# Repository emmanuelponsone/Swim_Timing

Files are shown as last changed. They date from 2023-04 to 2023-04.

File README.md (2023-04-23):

# Swimming Races timing system
Timing project for Swimming Races

**Watch video of the system working on field:**

https://youtu.be/FMHkYDIDqnM

Complete development of software and hardware for a system designed to meet the precision timing requirements of the international swimming federation. 

The software development involved:
- Development of firmware in C for 1 master microcontroller and 8 slave microcontrollers (ARM LPC1343 - Cortex M3).
- The master microcontroller reads a high-frequency timebase which is then divided and distributed to the slaves for synchronization.
- The slave microcontrollers, one for each lane of the pool, receive the synchronization signal as an interrupt and measure the time between button presses at the ends of the pool. The time data is reported to the master microcontroller.
- The master microcontroller receives the data from the slaves and sends the data to a PC via USB port.

On the PC:
- The PC software is responsible for managing the database and runs on a web environment on a RAILS server.
- Development of software in Ruby on Rails to create and maintain the database and display information on a web browser.
- Creating new scenarios (pools, length of each lane, number of lanes, laps per competition)
- Managing swimmers (age, gender, category, time records for each swim style, etc.)

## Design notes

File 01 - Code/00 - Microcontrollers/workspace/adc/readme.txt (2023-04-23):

adc
=====================
This project contains an ADC example for an LPCXpresso board.

It samples each ADC channel and plots the results in an ASCII
bargraph in the LPCXpresso Console using semihosted printf.

The project makes use of code from the following library project:
- CMSISv1p30_LPC13xx : for CMSIS 1.30 files relevant to LPC13xx

This library project must exist in the same workspace in order
for the project to successfully build.

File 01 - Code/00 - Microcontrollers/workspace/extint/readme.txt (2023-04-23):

extint
=====================
This project contains an external interrupt example for the LPCXpresso
board mounted with an LPC1343 Cortex-M3 part.

When downloaded to the board and executed, LED2 will be illuminated.
Then each time an external interrupt is triggered - by connecting P2.1
to ground - the state of LED2 will toggle.

The project makes use of code from the following library project:
- CMSISv1p30_LPC13xx : for CMSIS 1.30 files relevant to LPC13xx

This library project must exist in the same workspace in order
for the project to successfully build.

For more details, read the comments in config.h

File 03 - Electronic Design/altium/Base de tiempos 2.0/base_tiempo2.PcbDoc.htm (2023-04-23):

Reporting Options

# File in Previous Format

Date | : | 23/4/2023
Time | : | 13:04:47
Filename | : | C:\Users\hebertiponsone\Downloads\proyectofinal\altium\Base de tiempos 2.0\base_tiempo2.PcbDoc

Version | Warning
Summer 09 | CAUTION - File contains old violation objects. These violations are no longer supported & will not be loaded. Please run DRC after opening this file in order to refresh the violations.
Summer 09 | CAUTION - Existing testpoint rules and settings are used as fabrication testpoint information.
Release 12 | CAUTION - Air Gap Width previously controlled by Clearance rule is now controlled by Polygon Connect Style rule's newly introduced Air Gap Width (set to default value). Suggest reviewing each Polygon Connect Style rule's Air Gap Width attribute for correctness.
Release 13 | CAUTION - Silkscreen Over Component Pads Rules are converted to Silk To Solder Mask Clearance Rules. Suggest examining rule scopes for accuracy.

This file was generated by an earlier version of the software

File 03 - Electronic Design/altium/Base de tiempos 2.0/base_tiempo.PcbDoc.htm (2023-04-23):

Altium Reporting Options

# File in Previous Format

Date | : | 26/03/2012
Time | : | 10:34:26 a.m.
Filename | : | C:\Users\Emmanuel\Dropbox\proyectofinal\altium\Base de tiempos 2.0\base_tiempo.PcbDoc

Version | Warning
Summer 09 | CAUTION - File contains old violation objects. These violations are no longer supported & will not be loaded. Please run DRC after opening this file in order to refresh the violations.
Summer 09 | CAUTION - Existing testpoint rules and settings are used as fabrication testpoint information.

This file was generated by an earlier version of the software

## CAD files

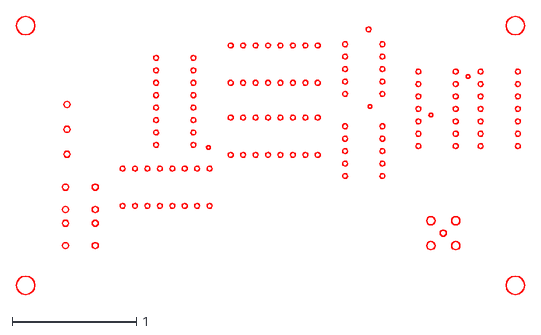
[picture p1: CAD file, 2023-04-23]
03 - Electronic Design/altium/Base de tiempos 2.0/agujeros_btiempos.dxf
4.09 x 2.24

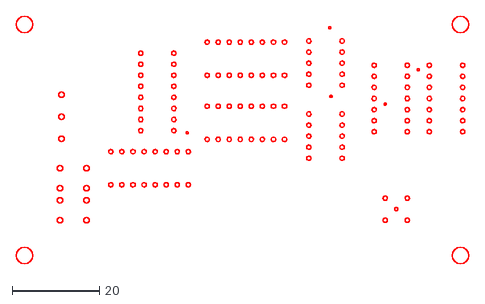
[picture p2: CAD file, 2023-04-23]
03 - Electronic Design/altium/Base de tiempos/cam.dxf
103.9 x 56.9

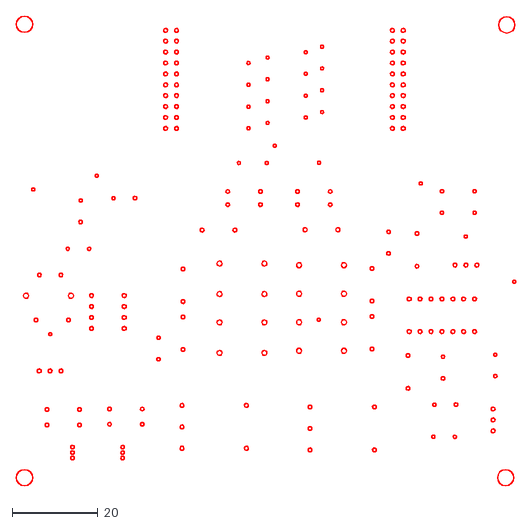
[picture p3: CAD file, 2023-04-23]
03 - Electronic Design/altium/caja de conexion/cam.dxf
116.4 x 109.5

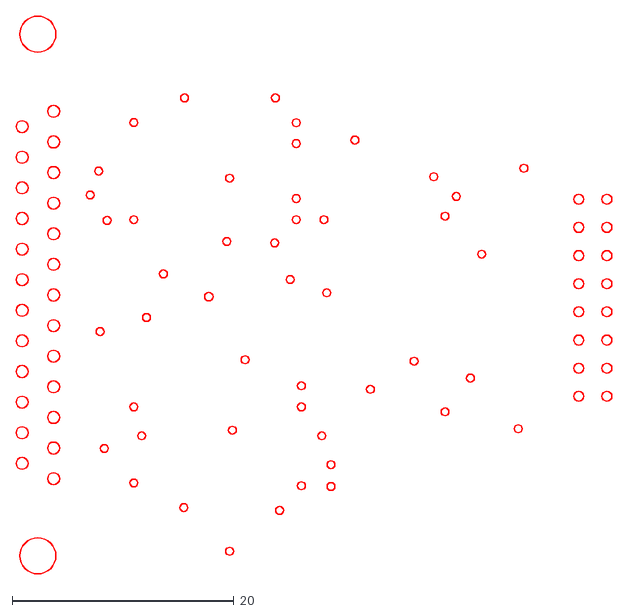
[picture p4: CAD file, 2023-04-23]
03 - Electronic Design/altium/Conexion unidad central/Filminas/adaptador lado unidad central/cam.dxf
53.7 x 50.3

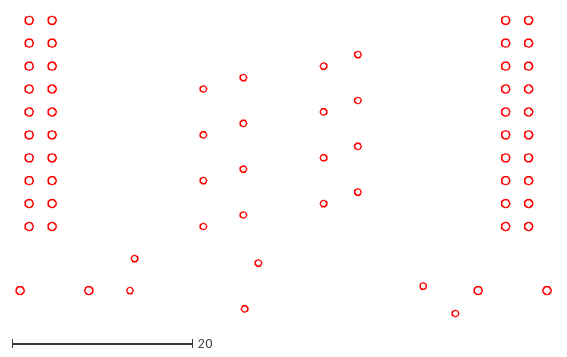
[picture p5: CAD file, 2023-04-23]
03 - Electronic Design/altium/Conexion unidad central/Filminas/caja de conexion/cam.dxf
59.3 x 33.3

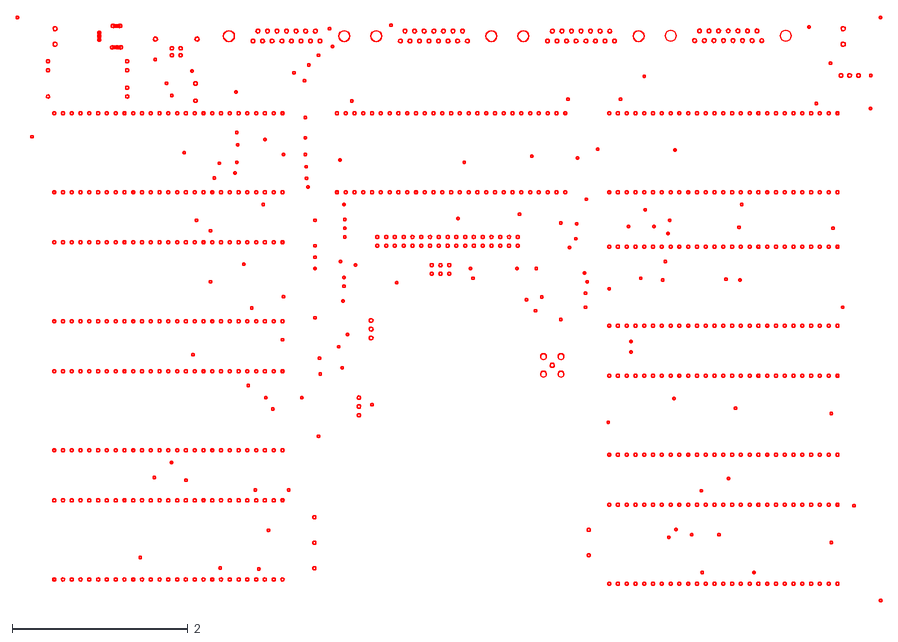
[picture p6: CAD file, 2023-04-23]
03 - Electronic Design/altium/Placa madre 2.0/filminas y nc drill/agujeros_placa_madre.dxf
9.86 x 6.67

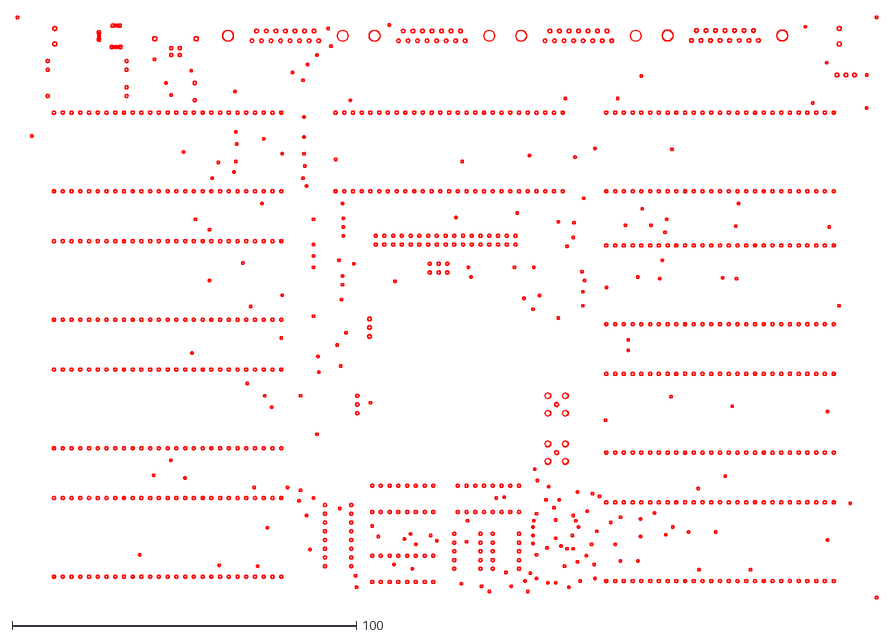
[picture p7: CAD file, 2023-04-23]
03 - Electronic Design/altium/Placa madre/filminas/cam.dxf
250.5 x 169.4

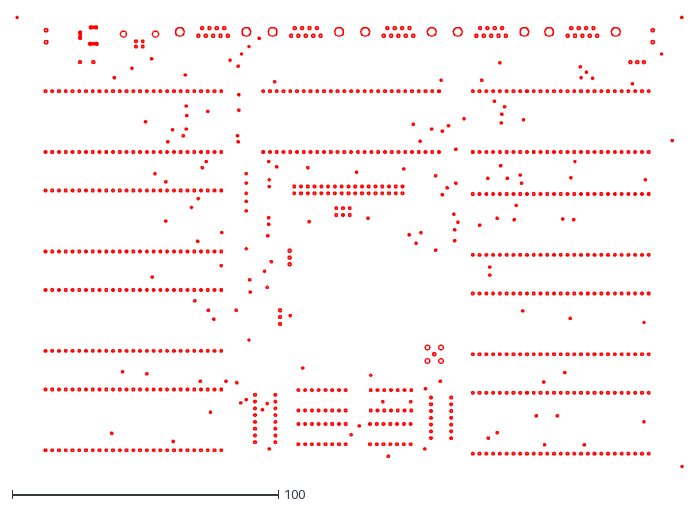
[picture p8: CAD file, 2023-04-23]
03 - Electronic Design/altium/Placa madre 2.0/cam.dxf
250.5 x 169.4

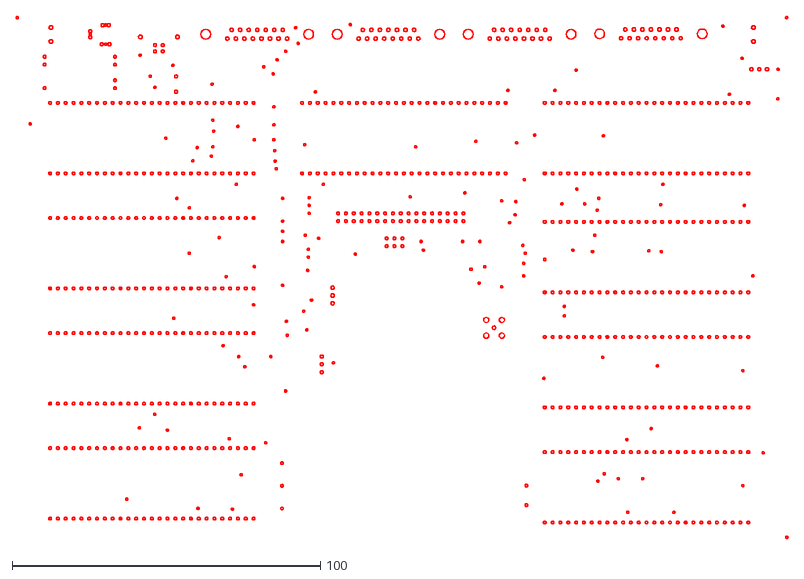
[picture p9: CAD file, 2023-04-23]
03 - Electronic Design/altium/Placa madre 2.0/agujeros_23.dxf
250.5 x 169.4

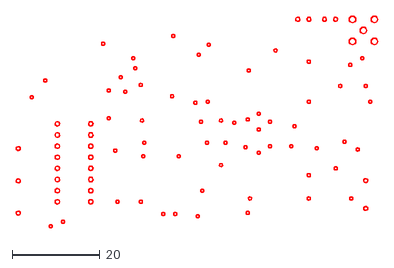
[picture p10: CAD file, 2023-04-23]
03 - Electronic Design/altium/Base de tiempos 2.0/agujeros.dxf
82.5 x 48.3

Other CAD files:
03 - Electronic Design/altium/Base de tiempos 2.0/agujeros_26_3.dwg
03 - Electronic Design/altium/Conexion unidad central/Filminas/adaptador lado unidad central/cam.dwg
03 - Electronic Design/altium/Conexion unidad central/Filminas/caja de conexion/cam.dwg
03 - Electronic Design/altium/Placa madre 2.0/agujeros_23.dwg
03 - Electronic Design/altium/Placa madre/filminas/cam.dwg

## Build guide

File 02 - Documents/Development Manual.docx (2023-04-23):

### tabla de contenidos

Desarrollo 2

Base de tiempos 3

Microcontroladores 6

Esquema general del sistema 8

PCB, esquemáticos y conexiones 9

Sistema operativo 10

Software 11

Placas de toque y pulsadores 12

Cables y conectores 14

Terminaciones en acrílico 15

Anexo: Código fuente 16

### desarrollo

El objetivo del presente texto es trazar una línea que una los primeros esbozos del proyecto con sistema terminado, justificando decisiones tomadas tanto en el ámbito técnico como en el económico del proyecto.

La idea surgió luego de tomar cuenta de la ausencia en el mercado de un sistema de cronometraje de natación de origen nacional que pueda satisfacer las demandas de una porción de mercado que no tiene acceso a equipos importados de elevado costo. Es así que se decidió apuntar a pequeños clubes, profesores de natación e instituciones deportivas barriales y/o comunales.

El primer punto a resolver fue entonces conocer las necesidades de estos potenciales clientes. Luego de realizar una encuesta a cerca de 30 profesores de natación, surgieron las siguientes características con las que debía contar el producto:

- La precisión en la toma de tiempos debía necesariamente compararse con los equipos profesionales, ya que los nadadores interesados en competir semi profesionalmente o profesionalmente van a llevar a cabo sus competencias en lugares donde se encuentren equipos profesionales homologados por la FINA y por lo tanto, el equipo con el que realicen sus entrenamientos debe registrar fielmente los tiempos de los mismos así como también poseer mecanismos de acción similares para facilitar la transferencia.
- El equipo no necesita estar homologado, ya que no va a ser utilizado para tomar tiempos oficiales.
- El manejo del equipo debe ser simple tanto en su hardware como en su software.
- El software debe permitir la gestión de una base de datos con la información de los nadadores, estilos, tiempos, etc.
- El equipo debe ser modular, es decir, tener la posibilidad de equipar desde un andarivel hasta ocho, para adaptarse a las necesidades económicas de cada cliente. Dicho de otra forma, que aquel que pueda equipar un solo andarivel, lo pueda hacer y con el tiempo ir añadiendo equipamiento para más andariveles.
- La seguridad de las personas apareció en reiteradas encuestas como una prioridad debido a que el equipo funcionará en ambientes de alta humedad.

Siguiendo estos lineamientos generales se comenzó con el desarrollo del proyecto.

### base de tiempos

La elección de la base de tiempos fue el aspecto técnico más importante a ser resuelto. El reglamento de natación de la FINA (Federación Internacional de Natación) en su inciso SW 11.2 fue lo que nos marcó las especificaciones con las que debía contar la base de tiempos. Dicha regla establece que el equipo debe ser capaz de garantizar el milisegundo aunque para la tabla de posiciones se usen las centésimas de segundo. Así, por ejemplo, tomando una carrera de 10 minutos de duración, el equipo debe tener una incertidumbre en la toma de tiempos menor a 10ppm, lo que equivale a decir que en esos 10 minutos, la incertidumbre sea menor a 1 milisegundo.

Surgió como primera opción utilizar un temporizador de un microcontrolador para llevar a cabo la toma de tiempos, sin embargo no cumplía con las condiciones propuestas por poseer una incertidumbre demasiado elevada, del orden de las 100ppm.

La solución adoptada fue la de diseñar una base de tiempos cuyo oscilador de referencia tuviese una incertidumbre menor a 10ppm. Luego de buscar varios modelos encontramos que el modelo que mejor se adaptaba a nuestras necesidades (principalmente debido a la deriva térmica) era el modelo FOX 924 (10MHZ – 2.5ppm). Se muestra a continuación los datos más relevantes del mismo:

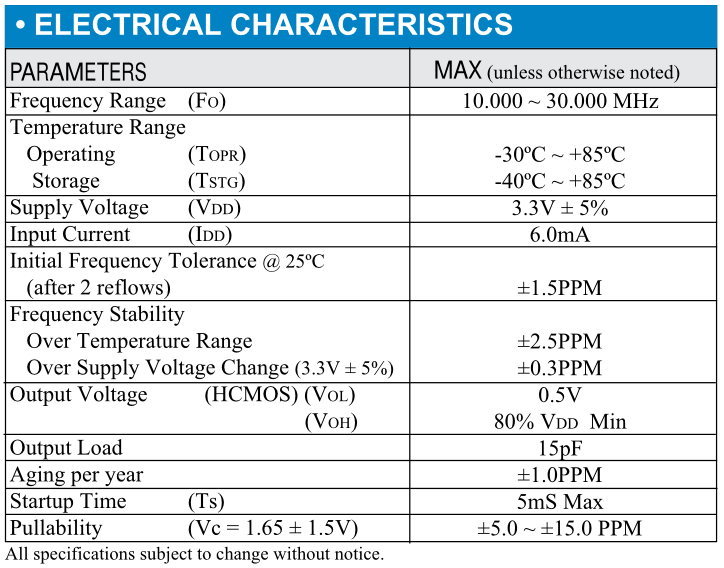
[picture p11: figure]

Ilustración 1: Especificaciones del Oscilador de Referencia

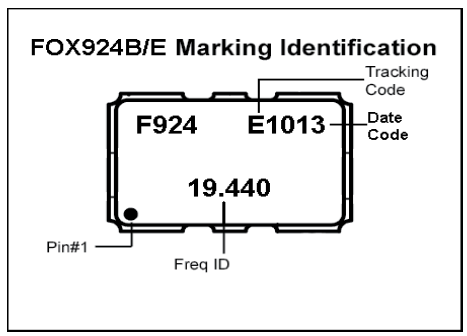
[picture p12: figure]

Ilustración 2: Layout del Oscilador

Si bien aún no habíamos tomado la decisión sobre qué microcontrolador utilizar, ya teníamos en claro que era imposible atacarlo con una base de tiempos de 10MHz y que debíamos bajar la frecuencia de la misma. Para ello se diseño un sistema de división de frecuencias basado en un contador binario de 14 bits seguido de una función lógica lograda mediante compuertas para reducir los 10MHz a 10KHz, frecuencia que resulta razonable para casi cualquier microcontrolador presente en el mercado actual. El esquema de división de frecuencias se presenta a continuación:

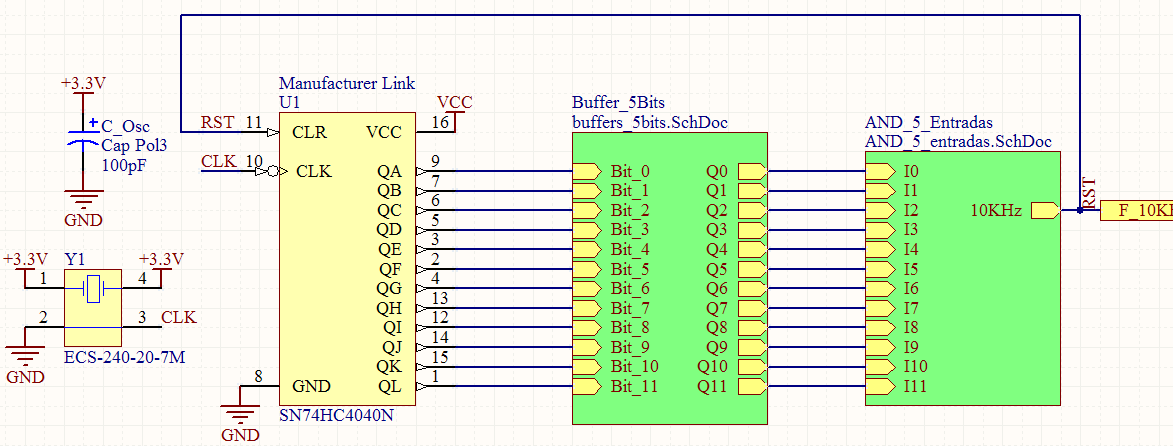
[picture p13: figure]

Ilustración 3: Esquemático de la Base de tiempos

Luego de fabricar un prototipo de la base de tiempos, se procedió a realizar las mediciones correspondientes para verificar si cumplía con las especificaciones.

Las mediciones se realizaron con un contador Tektronix CMC251, cuyas características son las siguientes:

- Número de dígitos: 8 más indicador de desborde.
- Frecuencia de la base de tiempo: 10MHz
- Incertidumbre de la base de tiempo: +/-1ppm
- Envejecimiento de la base de tiempo: +/-1ppm por año.
- Tiempo desde la adquisición del equipo: 5 años.

El objetivo de la medición era determinar la frecuencia del oscilador utilizado en el sistema de cronometraje de natación y poder evaluar si cumplía con los requisitos del proyecto. Recordemos que la máxima incertidumbre admitida es de +/-10ppm.

Esto significa que, al ser la frecuencia nominal del oscilador igual a 10MHz, se debe garantizar que el valor verdadero se encuentre en el intervalo 10MHz +/-10ppm. Es decir:

Fmin=10MHz-0.000100MHz=9.999900MHz

Fmax=10MHz+0.000100MHz=10.000100MHz

En resumen, buscábamos que la medición a realizar no solamente poseyera su valor nominal dentro de este intervalo, sino también que la ventana delimitada por la incerteza de la medición se encontrara dentro del intervalo requerido por el proyecto. De esta manera nos asegurábamos el cumplimiento de las especificaciones.

Para obtener máxima resolución y mínimo error en las mediciones se utilizó el frecuencímetro en modo frecuencia con un tiempo de compuerta de 10 segundos.

Como para este modo de operación, siendo la frecuencia incógnita aproximadamente 10Mhz, se contarán en 10 segundos 100 millones de pulsos, por lo tanto, el dígito más significativo se pierde, pero se sabe que es igual a la unidad. Dicho esto, el resultado de la medición fue:

f_(medida) =10.0000033MHz

Si ahora tenemos en cuenta que el error relativo de este instrumento se puede expresar como:

(∆f_x)/(f_x)=(∆f_(bt))/(f_(bt))+1/N

Siendo:

(∆f_(bt))/(f_(bt)):Error relativo de la base de tiempo del instrumento

1/N:Error de cuentización del insturmento. N:número de cuentas

Recordando que el error en la base de tiempo para el equipo recién calibrado es de +/-1ppm y que el equipo tiene 5 años de antigüedad, el error relativo total es de 6ppm.

Por último, el número de cuentas, N, es:

N=100000033→1/N≅0.001ppm

Por lo tanto, la incertidumbre relativa es:

(∆f_x)/(f_x)=6ppm+0.001ppm≅6ppm

Ahora podemos expresar el resultado de la medición como:

f_x =10.0000033MHz ±0.000060MHz

Del mismo pudimos concluir que la base de tiempos cumplía holgadamente con las especificaciones y, por lo tanto, era posible seguir avanzando en el proyecto teniendo total confianza en la calidad de uno de sus módulos críticos.

### microcontroladores

Era tiempo ahora de decidir sobre el tipo y el número de microcontroladores a utilizar. El primer esquema contemplaba el uso de un único microcontrolador el cual debía encargarse de:

- Comunicarse con la PC.
- Contar los pulsos de la base de tiempo.
- Recibir las señales de los 4 pulsadores de cada andarivel, es decir, un total de 32 pulsadores para el caso de 8 andariveles completos.
- Para cada andarivel contar los pulsos de la base de tiempos y registrar los tiempos cuando llegue cada señal de los pulsadores.
- Decidir para cada andarivel si daba prioridad a los pulsadores manuales o a las placas de toque.
- Recibir la señal del pulsador de largada, accionar la señal de largada.

Evidentemente las tareas a realizar eran demasiadas para ser llevadas a cabo por un único microcontrolador. Por ello se decidió utilizar un esquema en el que cada andarivel tendría asociado un microcontrolador el cual debería realizar las siguientes tareas:

- Recibir las señales de las dos placas de toque y de los dos pulsadores manuales.
- Contar los pulsos de la base de tiempos.
- Registrar los tiempos al momento de las pulsaciones.
- Comunicarse con un microcontrolador maestro para transmitirle los tiempos registrados.

Por otro lado, se contaría también, con un microcontrolador maestro, el cual se encargaría de realizar la sincronización de la unidad central y resolver las siguientes tareas:

- Comunicarse con la PC para enviar datos y recibir.
- Comunicarse con las unidades de cada andarivel para solicitar los tiempos de cada andarivel y transmitirle ciertos datos antes de comenzar la toma de tiempos.
- Registrar la señal de largada.

Con este nuevo esquema resulta razonable la carga asociada a cada microcontrolador al mismo tiempo que se garantiza la correcta adquisición de los datos.

Resumiendo, se optó por una unidad central que aloje a los 9 microcontroladores, que sea capaz de comunicarse con la PC y a la cual se conecten todos los pulsadores del sistema (Pulsadores manuales, placas de toque y señal de largada).

Una vez elegido el esquema a utilizar se procedió a seleccionar el tipo de microcontrolador. Como los miembros del grupo teníamos ya experiencia en la programación de la familia 8051 se optó en primera instancia por un Silabs F350.

Sin embargo, era necesario que el sistema se conectara a la PC mediante un puerto USB teniendo en cuenta la amplia difusión de este puerto en la gran mayoría de las computadoras. Lo cual no resultadaza para nada sencillo utilizando este tipo de microcontrolador. Por otro lado, la frecuencia de operación de este dispositivo no supera los 8MHz, valor que resulta algo justo teniendo en cuenta que las unidades dedicadas a cada andarivel no pueden darse el lujo de perder ni siquiera un pulso de la base de tiempos.

Estos inconvenientes llevaron a elegir un microcontrolador ARM, más precisamente, el LPC1343 que se consigue en el mercado local junto con su placa de desarrollo y programación por unos $120, evitando así tener que desarrollar una placa para alojar al dispositivo, ahorrando tiempo y dinero.

Entre las características que más nos interesaron de este sistema fueron:

- Facilidad de implementación de comunicación USB.
- Facilidad de implementación de la comunicación entre microcontroladores.
- Frecuencia de operación de 72MHz.
- Facilidad de programación.
- Precio.
- Calidad del PCB.
- Disponibilidad en el mercado local.

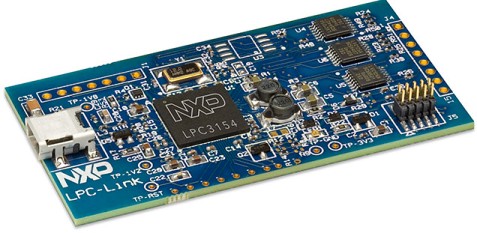
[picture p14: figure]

Ilustración 4: Programador del microcontrolador

### esquema general del sistema

Con la base de tiempos resuelta y los microcontroladores elegidos, procedimos a diseñar el esquema general del sistema, el cual se muestra a continuación:

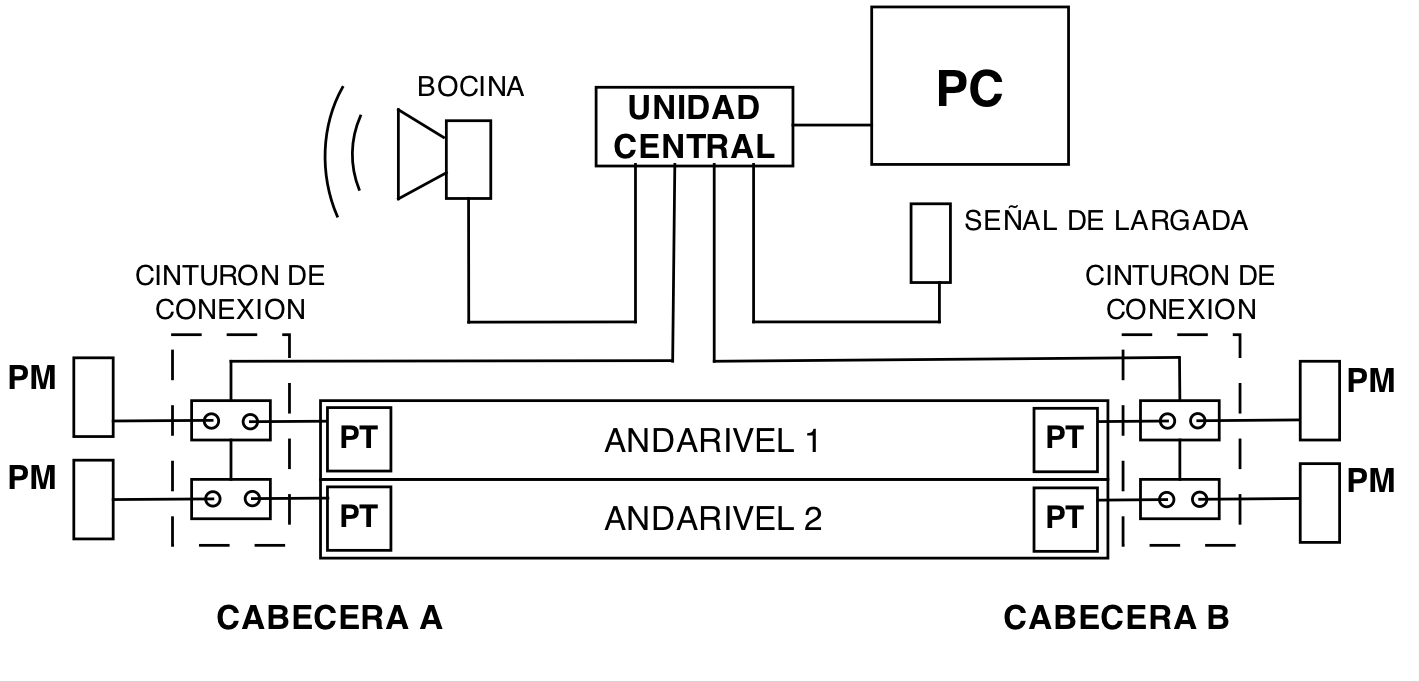
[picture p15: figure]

Ilustración 5: Esquema general del sistema

Se puede observar que la configuración adoptada es similar a la de los sistemas comercializados internacionalmente. Dicha decisión surgió como un lineamiento importante luego de realizar la encuesta a profesores y entrenadores de natación cuando, en resumen, mencionaron que se obtienen mejores rendimientos deportivos si durante los entrenamientos se consigue simular de la forma más aproximada el entorno de la competencia. Entendiéndose por ello placas de toque y bocina de largada entre otras cuestiones relacionadas más bien al estado mental del atleta.

### PCB, esquematicos y conexiones

Teniendo en cuenta que se decidió utilizar nueve módulos NXP LPC1343 surgió el problema del tamaño que debería tener el circuito impreso para alojarlos. El límite para el tamaño del circuito impreso está impuesto por el método serigráfico utilizado para su fabricación, es así que se puede alcanzar el tamaño de una hoja A4, es decir 30cm de alto por 21cm de ancho. Luego se procedió a la elección del gabinete teniendo en cuenta las medidas anteriores.

Con esta limitación se procedió a diseñar el circuito impreso, cuya versión final se muestra a continuación:

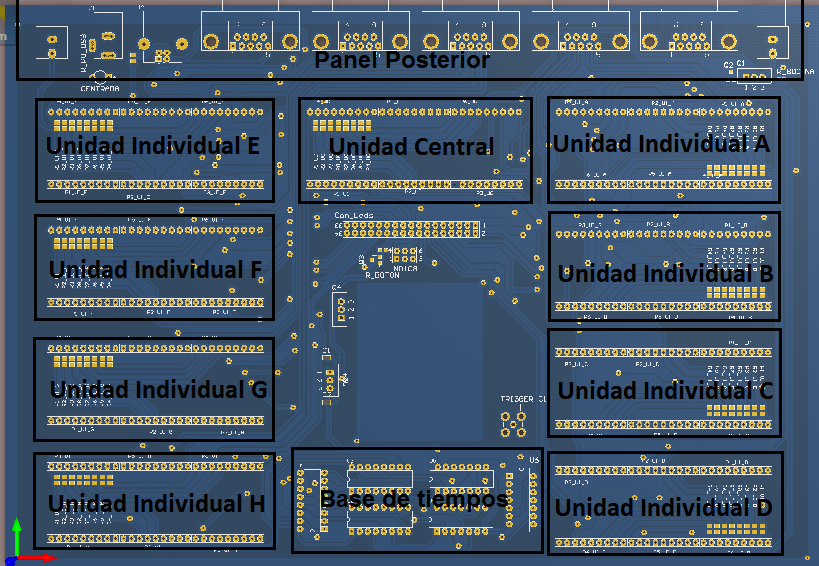
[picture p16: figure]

Ilustración 6: Vista frontal del Circuito impreso

Las conexiones en el panel posterior del gabinete se definieron como se muestra en la siguiente imagen:

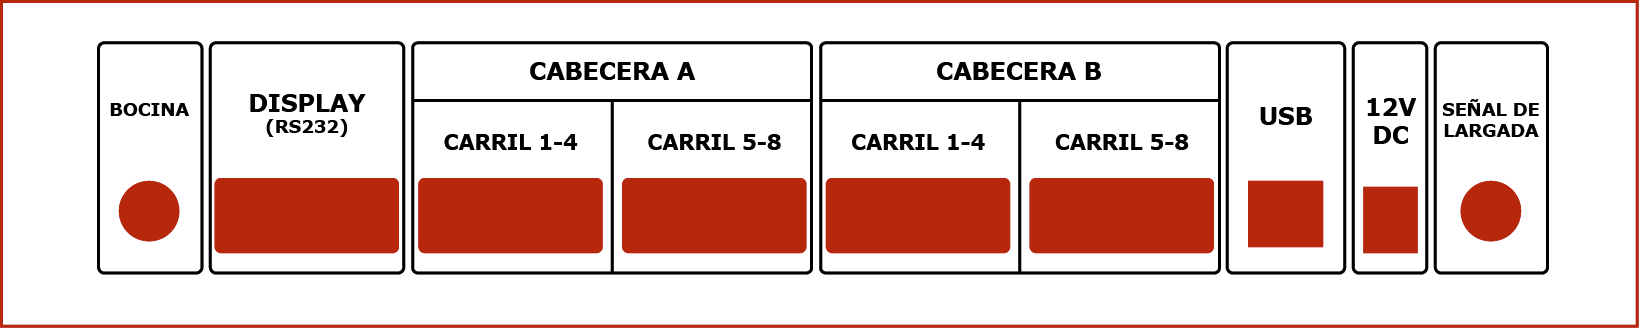
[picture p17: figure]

Ilustración 7: Vista del panel trasero

El diseño de los esquemáticos se realizó en Altium Designer Winter. Los distintos esquemáticos se muestran en las páginas siguientes.

### sistema operativo

La elección del SO resulto ser otro de los grandes problemas con el que nos encontramos, ya que si bien el sistema operativo más difundido es Windows, es Linux el que ofrece más posibilidades a la hora de programar y de realizar conexiones con dispositivos no convencionales, no requiere de drivers para manejar un puerto USB, etc.

Si bien los usuarios no suelen estar familiarizados con Linux, su uso se limitaría simplemente a utilizar el software provisto con el sistema de cronometraje, por lo que para el usuario no sería un problema mayor y para nosotros, sería mucho más simple la programación y conexión de los dispositivos. En definitiva, el usuario debería aprender a manejar solamente el programa, situación que sería igual en Windows, Linux u otro sistema operativo ya que se trata de una aplicación Web. Lo cual se traduce a que la operación del programa exactamente igual a navegar por Internet.

La distribución adoptada de Linux es la que se conoce como la más amigable de todas por poseer un entorno grafico muy intuitivo y depurado. La misma se llama Ubuntu y se ha comenzado a instalar en varios equipos de tiendas de electrodomésticos que venden computadoras por ser una alternativa legal y completa para cualquier uso, ya sea domestico o profesional.

### software

Este ítem resulta de especial importancia ya que es con el software de la PC con el que el usuario deberá interactuar, por lo tanto debe ser ágil, simple de utilizar y confiable.

En un primer momento se debió seleccionar un lenguaje o entorno de programación que nos permita hacer una interfaz grafica de usuario y que al mismo tiempo nos permita interactuar con bases de datos para guardar de forma ordenada los datos obtenidos.

Luego de presenciar una competencia de cierta importancia comprendimos que una herramienta muy útil sería utilizar Internet para la organización de las partidas del evento deportivo.

Con estos tres requerimientos presentes dimos con el entorno de desarrollo Web llamado Ruby on Rails, el cual permite crear grandes aplicaciones para Internet de forma sencilla, permitiendo a su vez interactuar con bases de datos a través de muchas herramientas completas y fáciles de usar.

El desarrollo de la aplicación se realizó en dos etapas bien diferenciadas. En la primera se buscó crear un núcleo capaz de crear, leer, modificar y destruir información en las tablas de la base de datos. Tarea sencilla pues para estos fines es que el entorno de Ruby on Rails fue pensado.

En una segunda etapa se busco desarrollar un medio por el cual la aplicación pueda tener una comunicación bidireccional con la Unidad Central, comenzando con transferencias sencillas y luego aumentando gradualmente la complejidad. En esta instancia se recurrió al lenguaje de programación C para crear un programa que se comunique con la Unidad Central y esta le transfiera los datos solicitados, escribiéndolos más tarde en un archivo para su posterior lectura. A continuación se muestra el esquema de comunicación:

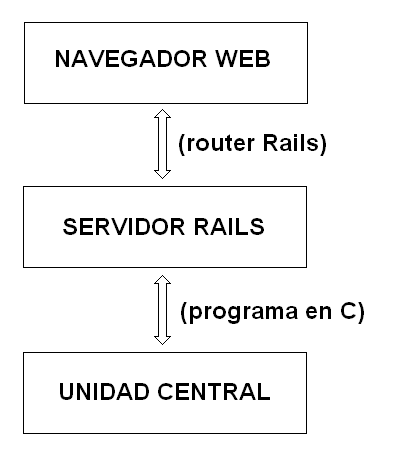
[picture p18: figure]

### Placas de toque y pulsadores

La placa de toque, al ser un dispositivo mecánico, fue el que más trabajo y dolores de cabeza nos dió, ya que nuestra especialidad es la electrónica, no la mecánica ni la carpintería.

Si bien ya teníamos cierta experiencia con este tipo de placas, ya que en un emprendimiento particular habíamos desarrollado una sistema de medición de saltos pliométricos, en el cual el deportista debe saltar sobre una plataforma la cual oficia también como pulsador, en nuestro caso la situación era distinta pues la placa de toque debería trabajar en el agua de forma semi-sumergida, ser impermeable, soportar los golpes del deportista y no activarse con el oleaje.

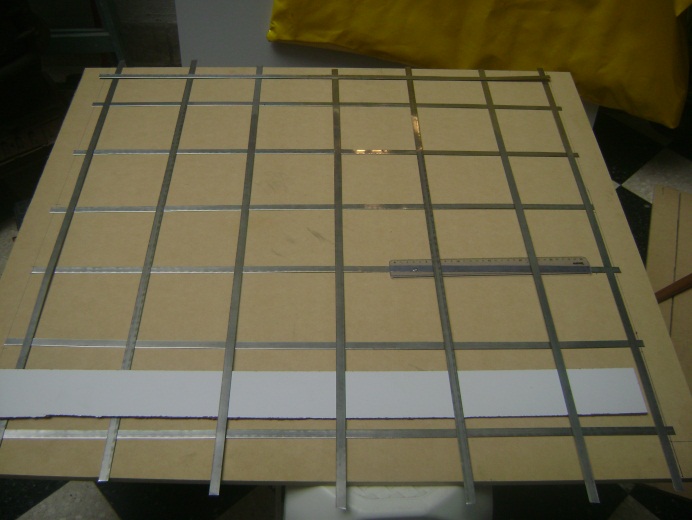
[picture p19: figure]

Se optó por construirla con dos placas paralelas de 1.1mts por 0.9mts de distinto grosor, el material ideal para la construcción de las placas es el PVC dada su durabilidad y características mecánicas, sin embargo, por su costo (aproximadamente $1500 para el par de placas) se optó por hacer el prototipo con placas de madera MDF. Cada placa alojaría varillas de acero inoxidable separadas equidistantemente, como se muestra a continuación:

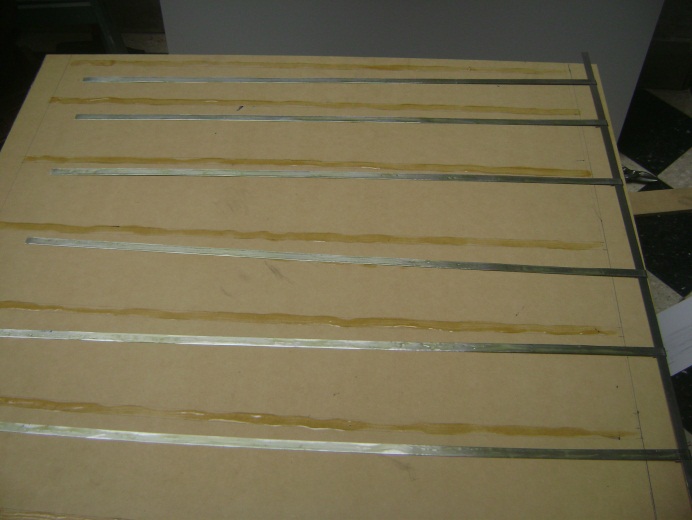
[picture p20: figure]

Ilustración 8: Vistas de las placas de toque

Para separar las placas y permitir que el pulsador funcione como normal abierto se utilizaron resortes dispuestos de la siguiente manera:

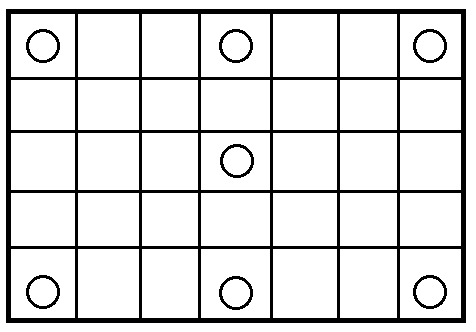
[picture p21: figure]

Ilustración 9: Esquema de posicionamiento de los resortes de separación

Por último, se unen las placas mediante bisagras tipo libro, las cuales le dan rigidez mecánica y facilidad de apertura a la hora de realizar reparaciones, protegiendo al mismo tiempo las soldaduras del cable con las varillas de acero inoxidable.

La funda, por otro lado, se envió a fabricar en un material sintético de alta resistencia (similar al de las bolsas de boxeo) cuyas uniones se realizan por costura y termo sellado, lo cual garantiza la impermeabilidad de la funda a la vez que su resistencia se ve mejorada. En la misma funda hay un compartimiento por donde pasar un caño para sujetar la placa de toque. La sujeción va a depender del natatorio donde se vaya a instala el equipo, por lo tanto es un ítem a solucionar en la etapa de instalación.

### cables y conectores

Los cables y los conectores utilizados tanto para las placas de toque como para los pulsadores manuales se ven expuestos no solo a condiciones de gran humedad, sino también de posibles pisadas por parte de los competidores y jueces. Por lo tanto se optó por la línea XLR, utilizados en lugares de alto tránsito y sometidos a esfuerzos considerables, como por ejemplo recitales. Son cables robustos, que al pisarlos y apretarlos no sufren daños. Sus conectores son realmente robustos, poseen ranuras que hacen imposible la tarea de conectarlo de manera errónea con lo cual resultan ideales para personal no calificado. Se muestran imágenes a continuación:

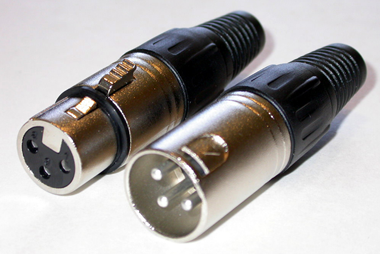
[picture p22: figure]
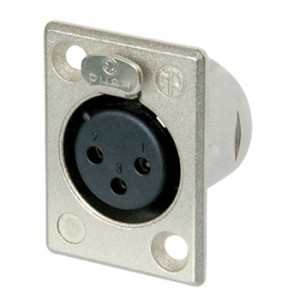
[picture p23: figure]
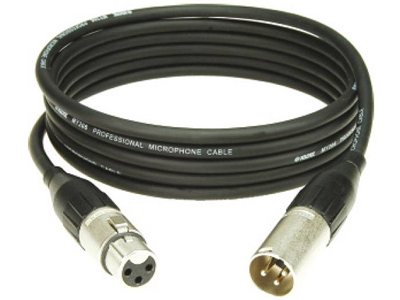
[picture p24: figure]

Ilustración 10: Conectores XLR

Para alojar los conectores dentro de las cajas de conexiones se diseñaron placas de montaje en aluminio las cuales fueron mecanizadas utilizando una CNC. Este último detalle permite darle mayor robustez al conjunto, cuestión que resulta ideal para encontrarse en un ambiente hostil.

### terminaciones en acrilico

Para terminar de darle al proyecto un aspecto más cuidado estéticamente y facilitar su uso se diseñaron frentes y piezas en acrílico para el gabinete y los pulsadores:

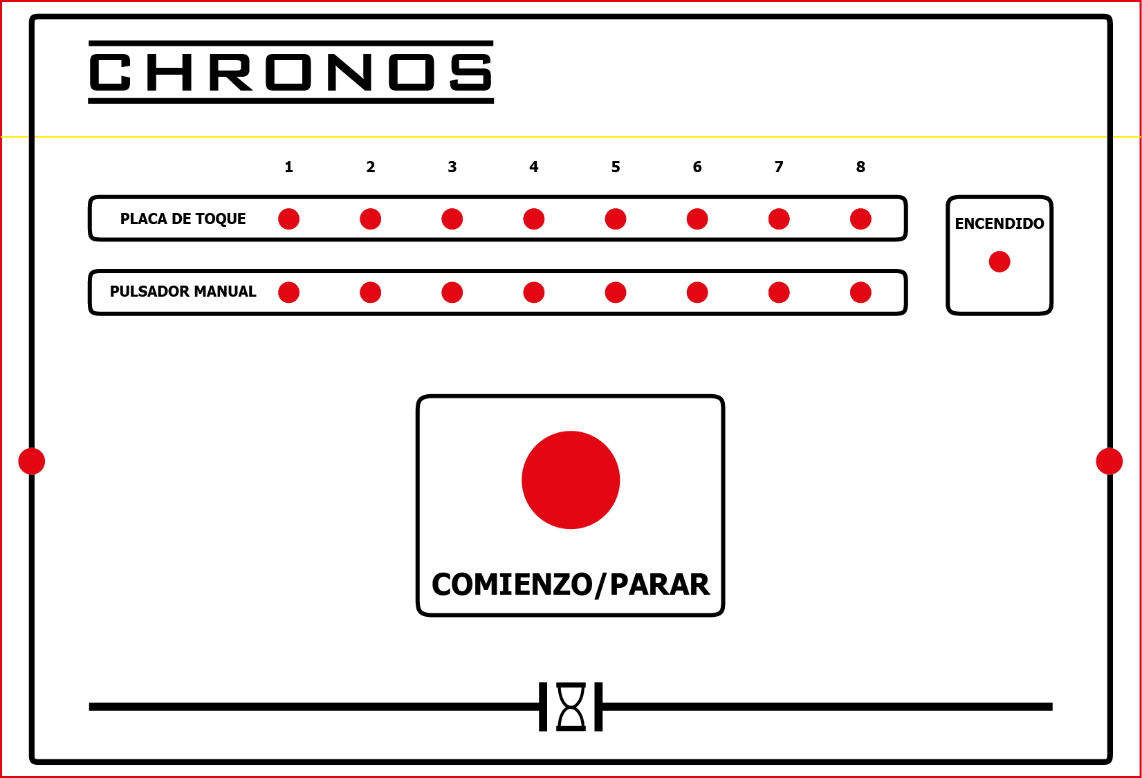
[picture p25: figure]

Ilustración 11: Diseño del Frente del gabinete en acrílico

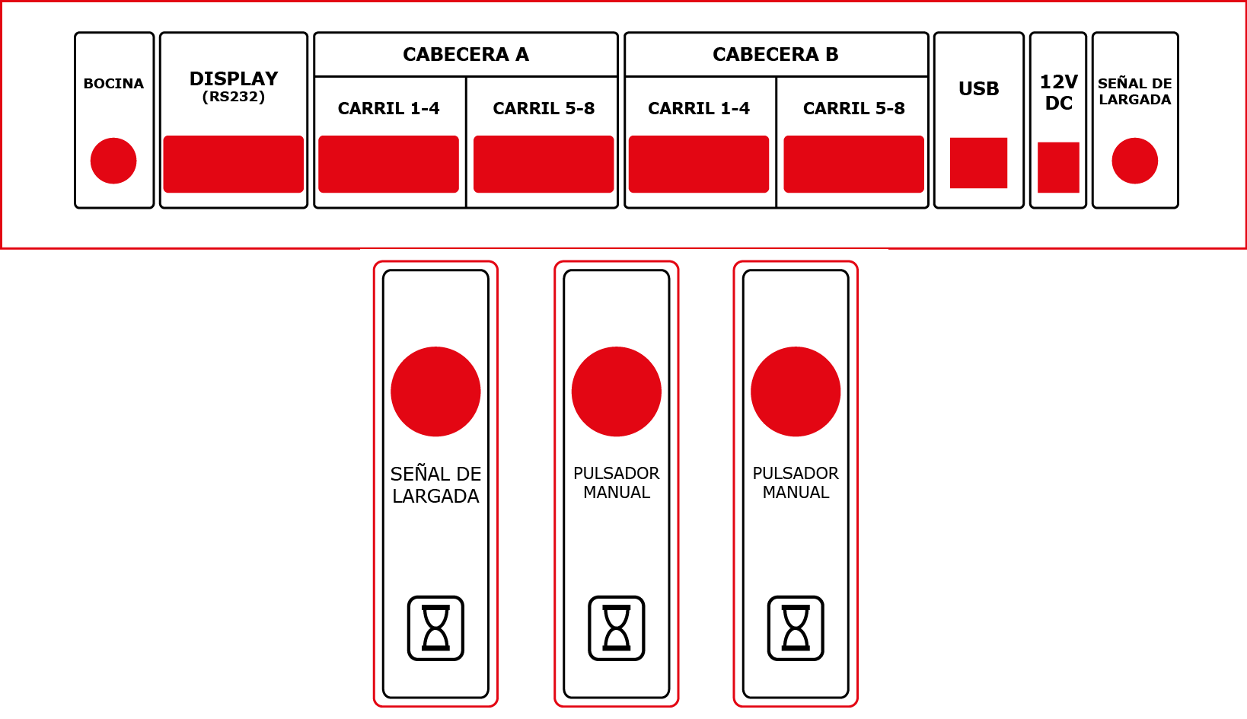
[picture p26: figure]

Ilustración 12: Diseño del acrílico posterior y de los pulsadores

Anexo: Código Fuente

Berti Ponsone, Emmanuel Hector 6/21 Reyes, Carlos Rodrigo

Sistema Automático de Cronometraje de Natación UTN - FRBA Manual de Desarrollo Materia: Proyecto Final Versión 1 Curso: R6052

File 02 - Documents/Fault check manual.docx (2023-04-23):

### manual de revisión de fallas

A continuación se da una lista de las fallas más comunes asociadas al sistema de cronometraje de natación y su posible solución. Es necesario antes de proceder a reparar la falla en cuestión verificar la existencia de dicha falla, es decir, reproducir la misma.

Este listado no pretende ser exhaustivo, sino contener los problemas más comunes que puede presentar el sistema de cronometraje y sus posibles soluciones. En caso de que se registre un problema no contemplado en este texto, el técnico encargado de la reparación del mismo debe documentar los pasos seguidos de forma tal que con el tiempo y la experiencia cotidiana se puedan registrar la mayor cantidad de fallas posibles y sus soluciones, ahorrando así tiempo en reparaciones futuras.

1. El equipo no enciende.

Posibles causas y soluciones:

  a. Defectos en la fuente de alimentación externa.
    i. Solución: Verificar la tensión de salida de la fuente. Si no es la nominal, sustituir la misma. Si el problema no se solucionó, ir al siguiente paso.
  b. Pistas Cortadas.
    i. Solución: Verificar la continuidad en las pistas asociadas a las tensiones de 12Vcc, 5Vcc y 3.3Vcc. Si el estado de las pistas es correcto, ir al siguiente paso.
  c. Defectos en los reguladores lineales.
    i. Solución: Verificar la tensión de salida de los reguladores de 5Vcc y de 3.3Vcc. En caso de que los valores medidos no sean los esperados, remplazar los reguladores. Si el problema no se solucionó, ir al siguiente paso.
  d. Defectos en las unidades individuales y/o en la unidad central.
    i. Solución: Retirar todas las unidades, conectar la fuente de alimentación externa y medir las tensiones en los puntos de 12Vcc, 5Vcc y 3.3Vcc. Si son las correctas, ir colocando de a una las unidades y midiendo cada ves las tensiones correspondientes. En caso de detectarse alguna falla al momento de conectar una unidad, remplazar la misma y seguir con el resto. Si el problema no se solucionó, ir al siguiente paso.
  e. Errores en la placa madre.
    i. Solución: Remplazar la placa madre.
2. Los tiempos medidos son claramente erróneos.

Posibles causas y soluciones:

  a. La tensión de alimentación de la base de tiempos no es correcta.
    i. Solución: Desarmar el gabinete del sistema y medir la tensión de salida del regulador que alimenta al oscilador. Si la misma no es la nominal (3.3Vcc), remplazar el regulador. Una ves remplazado, efectuar la medición correspondiente a la base de tiempos utilizando la guía del anexo 1. Si el problema persiste, ir al siguiente paso.
  b. El oscilador de referencia se ha dañado.
    i. Solución: Remplazarlo. Realizar la medición cuya guía se encuentra en el anexo 1. Si el problema persiste, ir al siguiente paso.
  c. Las unidades individuales están contabilizando mal los pulsos de la base de tiempos.
    i. Solución: Remplazar las unidades individuales que presenten el problema y probar el sistema completo. Si el problema persiste, ir al siguiente paso.
  d. Errores en la placa madre.
    i. Solución: Remplazar la placa madre.
3. Los pulsadores manuales/placa de toque no funcionan.

Posibles causas y soluciones:

  a. Se ha cortado un cable.
    i. Solución: Probar con un multímetro la continuidad de los cables de los pulsadores/placa de toque. En caso de que no haya continuidad remplazar el cable. Si el problema persiste, ir al siguiente paso.
  b. Pistas cortadas en la placa madre.
    i. Solución: Revisar si en las pistas asociadas a los pulsadores/placas de toque no hay cortes, en caso de existir, repararlos de ser posible. Si las pistas se encuentran en buen estado, ir al siguiente paso.
  c. Las unidades individuales/unidad central no detectan las pulsaciones.
    i. Solución: Verificar con un multímetro que al presionar un pulsador, se detecte un cambio en el voltaje del pin asociado de cada placa, si se verifica este cambio indica que las señales llegan correctamente a las unidades, sin embargo, estas no las detectan. De ser así, remplazar la unidad en cuestión.
4. No hay comunicación entre la PC y el sistema de cronometraje.

Posibles causas y soluciones:

  a. El puerto USB de la PC se ha dañado.
    i. Solución: Verificar, utilizando una PC distinta que el sistema se comunica correctamente. Si es así, avisar al cliente que el problema se encuentra en su PC. Si el problema persiste, ir al siguiente paso.
  b. La unidad central se ha dañado.
    i. Solución: desarmar el gabinete y remplazar la unidad central.

Anexo 1

Para que el equipo cumpla con las especificaciones debe verificarse que la incertidumbre asociada a la base de tiempos sea menor a 10ppm. Para ello es necesario realizar una medición de la misma utilizando un frecuencímetro digital, el cual deberá encenderse al menos 1 hora antes de ser llevada a cabo la medición para garantizar así la estabilización del equipo.

Una ves estabilizado el equipo, se procederá con la medición en cuestión. Para ello hay que conectar al frecuencímetro la base de tiempos de la placa madre mediante un cable adecuado. El conector que se muestra a continuación en la placa madre es el que contiene la señal a medir:

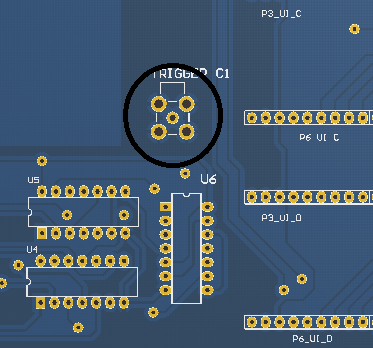
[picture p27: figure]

Ilustración 1: Señal del oscilador

En el laboratorio se cuenta con un frecuencímetro Tektronix CMC251, cuyas características son las siguientes:

- Número de dígitos: 8 más indicador de desborde.
- Frecuencia de la base de tiempo: 10MHz
- Incertidumbre de la base de tiempo: +/-1ppm
- Envejecimiento de la base de tiempo: +/-1ppm por año.
- Tiempo desde la adquisición del equipo: R años (Considerar R como el número de años desde 2006 a la fecha de medición).

Al ser la frecuencia nominal del oscilador igual a 10MHz, se debe garantizar que el valor verdadero se encuentre en el intervalo 10MHz +/-10ppm. Es decir:

- Fmin=10MHz-0.000100MHz=9.999900MHz
- Fmax=10MHz+0.000100MHz=10.000100MHz

En resumen, buscamos que la medición a realizar no solamente posea su valor nominal dentro de este intervalo, sino también que la ventana delimitada por la incerteza de la medición se encuentre dentro del intervalo requerido por el proyecto. De esta manera nos aseguraremos el cumplimiento de las especificaciones.

Para obtener máxima resolución y mínimo error en las mediciones se utilizará el frecuencímetro en modo frecuencia con un tiempo de compuerta igual a 10 segundos.

Para este modo de operación, siendo la frecuencia incógnita aproximadamente 10Mhz, se contarán en 10 segundos 100 millones de pulsos, por lo tanto, el dígito más significativo se pierde, pero se sabe que es igual a la unidad. Teniendo en cuenta esto, anotar a continuación el resultado de la medición:

f_(medida) =_____________________________MHz

Si ahora tenemos en cuenta que el error relativo de este instrumento se puede expresar como:

(∆f_x)/(f_x)=(∆f_(bt))/(f_(bt))+1/N

Siendo:

(∆f_(bt))/(f_(bt)):Error relativo de la base de tiempo del instrumento

1/N:Error de cuentización del insturmento. N:número de cuentas

Si recordamos que el error en la base de tiempo para el equipo recién calibrado es de +/-1ppm y que el equipo tiene R años de antigüedad (2006 a la fecha de medición), el error relativo total es de (R+1)ppm.

Por último, el número de cuentas, N es:

N=___________________→1/N≅_______________ppm

Por lo tanto, la incertidumbre relativa es:

(∆f_x)/(f_x)=(R+1)ppm+1/Nppm≅X ppm

Ahora podemos expresar el resultado de la medición como:

f_x =f_(medida) ±X ppm

Si se verifica que el valor fx se encuentra dentro del rango 9.999900MHz – 10.000100MHz, la incertidumbre asociada a la base de tiempos respeta las especificaciones. En caso contrario, cambiar el oscilador y realizar nuevamente las mediciones.

1 de 5 Berti Ponsone, Emmanuel Hector Reyes, Carlos Rodrigo

Sistema Automático de Cronometraje de Natación UTN - FRBA Manual de Revisión de Fallas Materia: Proyecto Final Versión 1 Curso: R6052

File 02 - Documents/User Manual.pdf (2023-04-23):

## MANUAL DE USUARIO

## SISTEMA DE CRONOMETRAJE PARA PILETAS CHRONOS

Usted acaba de adquirir el sistema automático de cronometraje para piletas y es nuestro deseo hacerle llegar nuestras más sinceras felicitaciones. Estamos seguros que no se arrepentirá de su inversión pues la satisfacción total del cliente es uno de nuestros ejes como empresa.
Esperamos que disfrute plenamente del producto y que si tiene alguna sugerencia no dude en contactarnos para ayudarnos a mejorar y perfeccionar nuestros equipos.

Tabla de contenidos

Nomenclatura básica

4
Conexión del sistema

7
Descripción del sistema

8
Uso de la unidad central

9
Descripción general

9
Panel trasero

9
Indicaciones lumínicas | 10
Botón de la unidad central | 10
Uso del programa | 12
Descripción general | 12
Nadadores | 13
Agregar un nadador | 13
Ver nadadores | 13
Editar un nadador | 14
Borrar un nadador | 1
| 5
Entrenamientos | 1
| 6
Descripción general | 1
| 6
Agregar un entrenamiento | 1
| 6
Adquisición de tiempos | 1
| 7
Ver entrenamiento | 1
| 8
Borrar un entrenamiento | 1
| 8
Competencias | 20
Descripción general | 20
Agregar una competencia | 20
Ver una competencia | 21
Editar una competencia | 22
Borrar una competencia | 22
Agregar una partida | 23
Adquisición de tiempos | 25
Ver una partida | 26
Borrar una partida | 26
Mantenimiento y cuidados del sistema | 28
Placas de toque | 28
Unidad central | 28
Cables y conectores | 28
Pulsadores manuales | 29
Fallas comunes y soluciones | 30
Especificaciones técnicas | 31
Contacto | 32

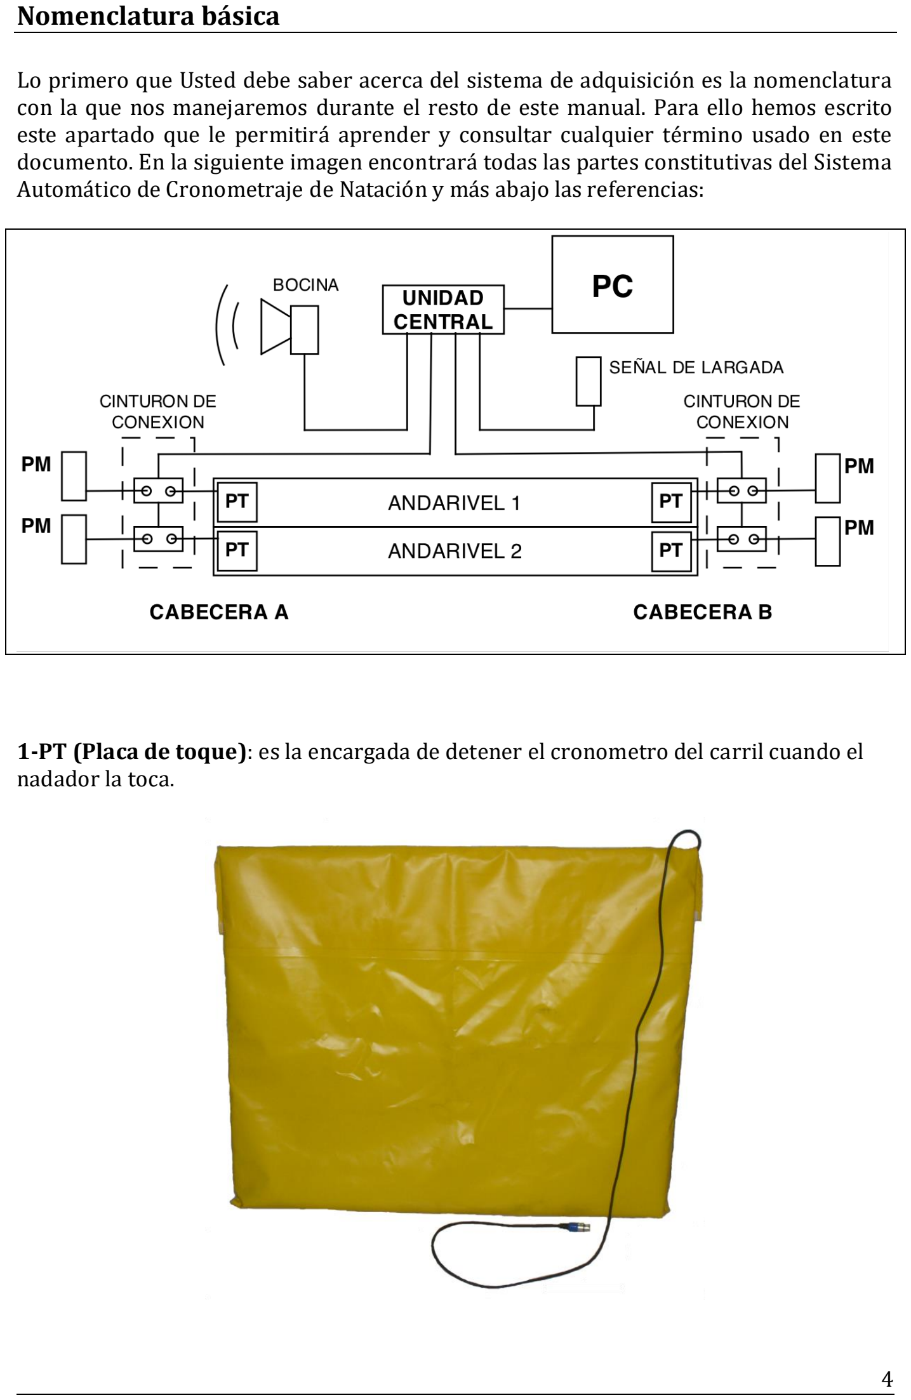
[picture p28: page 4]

Nomenclatura básica

Lo primero que Usted debe saber acerca del sistema de adquisición es la nomenclatura con la que nos manejaremos durante el resto de este manual. Para ello hemos escrito este apartado que le permitirá aprender y consultar cualquier término usado en este documento. En la siguiente imagen encontrará todas las partes constitutivas del Sistema Automático de Cronometraje de Natación y más abajo las referencias:

1-PT (Placa de toque): es la encargada de detener el cronometro del carril cuando el nadador la toca.

2-PM (Pulsador manual): es el mando que utilizará el juez del carril para detener el cronometro en caso de que la placa de toque falle. También se utiliza por el juez de la competencia para comenzar a correr los cronómetros.

3-Unidad central: contiene los cronómetros de cada andarivel, comanda las leyendas del display y se comunica con la computadora para transferir los datos.

4-Bocina: tiene por fin dar una señal auditiva a los nadadores para la largada.

5-Cinturones de conexión: se encarga organizar los cables de las placas de toque y los pulsadores manuales de una cabecera de la pileta correspondientes a un grupo de andariveles (1-4 o 5-8).

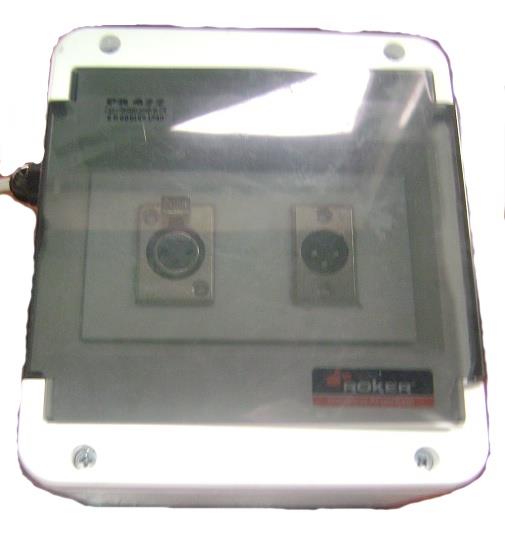
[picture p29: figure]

Se debe prestar especial atención a que a cada cabecera se la denomina A o B. Siempre se debe procurar que el o los nadadores comiencen a nadar desde la cabecera A, pues el sistema espera que primero sean accionadas las placas de toque y/o los pulsadores manuales de la cabecera B.

ATENCION: los nadadores siempre deben comenzar a nadar

partiendo desde la cabecera A.

Conexión del sistema

El conexionado del sistema para su uso (entrenamiento o competencia) es realmente muy sencillo y consta de unos pocos pasos.

Conexión de pulsadores manuales y placas de toque

1. Con las placas de toque instaladas en la pileta y los pulsadores manuales al lado del partidor conectar ambos a la caja de conexión respetando las leyendas.
2. Con las placas de toque y los pulsadores manuales conectados a las cajas de conexión se debe conectar los cinturones de conexión en la Unidad Central respetando la cabecera y número de andarivel guiándose para ello en las leyendas que figuran en la Unidad Central.
3. Conectar el pulsador manual del juez de competencia en la Unidad Central.
4. Verificar el correcto funcionamiento utilizando los leds de la Unidad Central (ver el apartado Indicaciones Lumínicas).
5. Conectar la bocina a la unidad central.
6. Conectar el display a la unidad central.
7. Conectar la fuente de alimentación a la unidad central.
8. Conectar la unidad central a la computadora por medio del USB.

Antes y después de utilizar el equipo se recomienda inspeccionar visualmente las fundas de las placas de toque, los cinturones de conexión y todos los cables y conectores en busca de daños por desgaste anormales para conseguir su reemplazo de ser necesario.

CONSEJO: sea metódico y siempre realice las conexiones de manera

secuencial para disminuir el riesgo de equivocación.

Descripción del sistema

Desde el tablero de diseño hasta que el equipo ha llegado a sus manos cada detalle ha sido cuidadosamente pensado para obtener un equipo de fácil manejo, alta confiabilidad y bajo costo. Por eso es importante que Ud. comprenda en su totalidad al sistema de cronometraje, ya que de eso depende que pueda sacarle el máximo provecho en diferentes situaciones (entrenamientos o competencias).
Los cronómetros de cada andarivel se encuentran en la unidad central y la placa de toque simplemente oficia de botón al igual que el pulsador manual. Podría pensarse al sistema como un cronómetro convencional de mano (de mucha mayor precisión) pero con la diferencia que el Start lo da el juez de competencia con la señal de largada y el Stop lo da el nadador al tocar la placa de toque o el juez de carril al presionar su pulsador manual.
Habiendo aclarado este punto hablemos el roll que cumple la computadora. La PC se sincroniza con la Unidad Central para mostrar los tiempos que fueron adquiridos y luego los almacena en una base de datos para mantener un registro ordenado de los distintos eventos que hayan sucedido (entrenamientos o competencias). Sin una PC la toma de tiempos no puede tener lugar pues existe información como el número de laps que ser conocidos por la unidad central para determinar el fin de la competencia.
En cambio el display puede o no estar presente, ya que solo se encarga de exhibir los tiempos transcurridos en cada andarivel y son los que envía la unidad central.

Uso de la Unidad Central
Descripción general
La Unidad Central es el corazón del sistema. En este dispositivo se cronometran los tiempos correspondientes que luego serán transmitidos a la computadora para su posterior almacenamiento.
Su uso es muy sencillo ya que consta de un solo botón (COMIENZO/PARAR) que se usa en los entrenamientos o competencias para:
- Dejar el sistema a la espera, para que el juez de competencia dé la orden de largada;
- Parar la competencia ante una partida en falso por ejemplo y que la prueba pueda reanudarse.

Panel trasero
La parte trasera de la Unidad Central se denomina Backend, la misma sirve para conectarse con los distintos periféricos como el display, cinturones de conexión, fuente de alimentación, etc.
Las conectores utilizados están pensados para evitar la errónea conexión de dispositivos. Para ayudar en la puesta a punto del sistema existen las leyendas, a las que se debe prestar especial atención al momento de conectar los periféricos a fin de asegurar que, por ejemplo, los cinturones de conexión sean conectados donde deben. Caso contrario el sistema no funcionará correctamente.
Si observamos la siguiente imagen veremos el panel con sus leyendas.

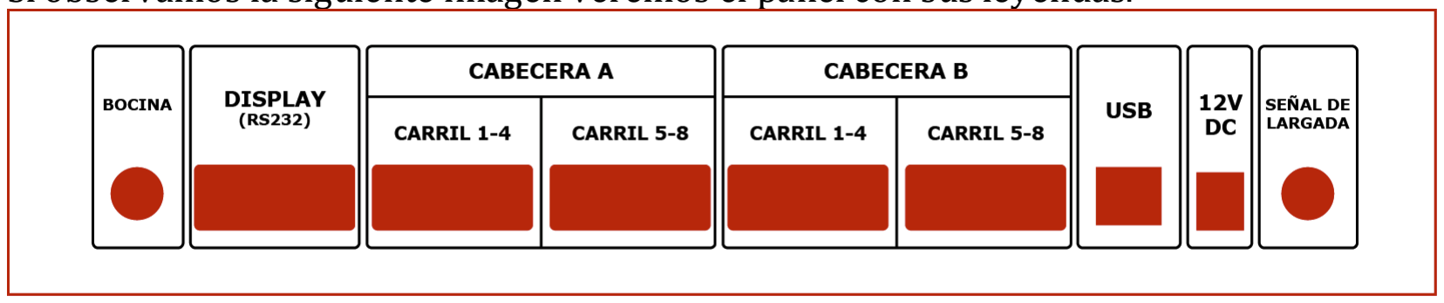
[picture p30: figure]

A continuación se realiza una lista de los conectores que aparecen en la figura anterior de izquierda a derecha:
- Conector de bocina de largada
- Conector de display
- Conector de CABECERA A para cinturón de conexión de los andariveles 1 a 4
- Conector de CABECERA A para cinturón de conexión de los andariveles 5 a 8
- Conector de CABECERA B para cinturón de conexión de los andariveles 1 a 4
- Conector de CABECERA B para cinturón de conexión de los andariveles 5 a 8
- Conector USB para la PC
- Conector de la fuente de alimentación
- Conector del pulsador manual del juez de competencia para dar la señal de largada Los cinturones de conexión deben ser conectados con especial cuidado, puesto que de esto depende que la adquisición de tiempos sea la que se espera y no otra cosa. Recomendamos utilizar las indicaciones lumínicas (ver la sección Indicaciones Lumínicas) para asegurarse que esta tarea fue realizada correctamente y al mismo tiempo verificar el funcionamiento de conectores y cables.
También se debe prestar atención a la forma de las fichas y a su sentido de conexión. Si se observan los conectores de los cinturones de conexión y al conector del display se apreciará que tienen un solo sentido de conexión. Estas fichas simplifican la tarea de conexión y la hacen más sencilla evitando errores indeseados.

En el caso de los restos de los conectores no es posible conectarlos de forma errónea puesto que las fichas no son compatibles. Esto ha sido pensado de esta manera para simplificar la tarea de conexión al hacerla más intuitiva.

Indicaciones lumínicas
La unidad central cuenta con indicaciones luminosas mediante LEDs, los cuales tienen por objetivo brindar información referente al estado de cables, placas de toque, pulsadores manuales y alimentación. Esta funcionalidad resulta muy útil para realizar verificaciones sobre el funcionamiento del sistema antes de una competencia o entrenamiento.
Veamos el frente del equipo:

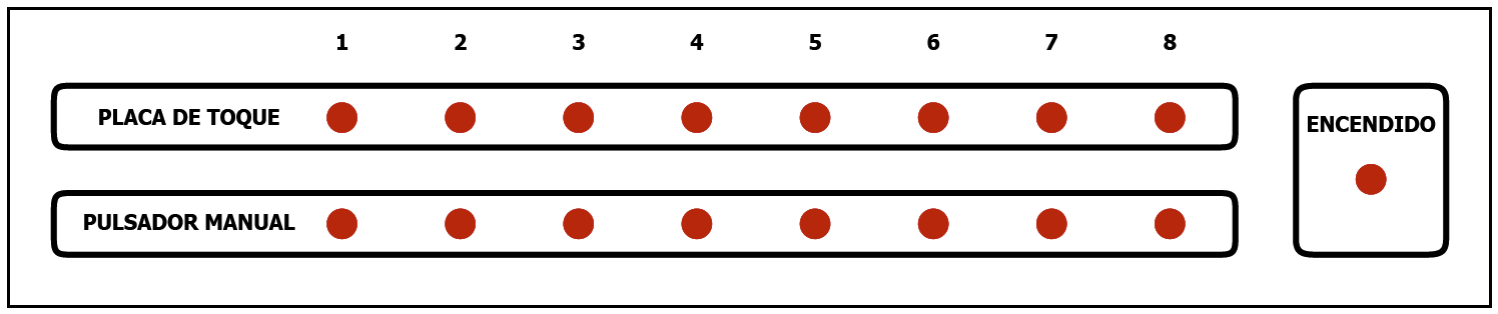
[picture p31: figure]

En la figura anterior se puede apreciar un recuadro con la leyenda “ENCENDIDO”, lo cual indica que el equipo se encuentra con la alimentación conectada y listo para ser usado.
Por otro lado observamos dos filas de ocho LEDs cada una. El uso de las mismas es sumamente sencillo y fue pensando para realizar la puesta a punto del sistema antes de una competencia o entrenamiento.
Veamos la fila “PLACA DE TOQUE” con mayor profundidad. Sobre cada LED existe un número que se corresponde con el andarivel al que hace referencia la luz. La misma se encenderá cada vez que sea presionada una placa de toque de un mismo andarivel sin importar si fue la de una u otra cabecera. Esta luz permanecerá encendida mientras se mantenga presionada la placa de toque.
De forma similar funciona la fila “PULSADOR MANUAL”. Es decir que si por ejemplo se acciona un pulsador manual del andarivel 2 (indistintamente de la cabecera de la pileta) se encenderá el LED correspondiente a la segunda columna dentro del recuadro “PULSADOR MANUAL” y se apagará al soltar el mismo.
Como aclaración final es necesario mencionar que las luces funcionarán de similar manera en el caso de que se encuentre equipada una sola cabecera de la pileta. Por lo tanto no es necesario instalar el sistema completo en todos los andariveles y en ambas cabeceras si así no lo requiere la competencia o entrenamiento.

Botón de la unidad central
Este es el único botón que posee la unidad y tiene tres funciones a saber:
- Dejar la unidad central a la espera de la señal de largada del juez se competencia. Es decir dejar lista al sistema para la adquisición de tiempos.
- Parar la adquisición de tiempos.
- Resetear los tiempos adquiridos luego de haber parado la toma de tiempos. Luego de que en el programa que han realizado las configuraciones necesarias, luego los tiempos deben ser adquiridos, para ello la unidad debe estar preparada. Esto significa que el operador debe hacerle saber al equipo que desea tomar tiempos en ese momento. Para ello debe presionar el botón de la unidad central luego de estar posicionado en la vista correspondiente al entrenamiento o partida que desea ejecutar. A continuación el sistema esperará la señal de largada que proviene del pulsador manual del juez de competencia, y recién ahí comenzará la adquisición de tiempos. Luego la toma de tiempos finalizará automáticamente luego que el o los nadadores completen los laps establecidos en el programa.
Sin embargo puede darse que el entrenamiento o la partida deba ser detenida y reiniciada debido a una partida en falso por ejemplo. En tal caso, primero se debe detener la toma de tiempos en curso. Esta acción se realiza presionando dos veces el botón de la unidad central. Esto es así para evitar que un toque accidental comprometa la adquisición. A continuación el entrenamiento o partida deberá ser reiniciado, para ello primero se deben resetear la unidad central, lo cual se realiza presionando tres veces el botón de la unidad central. Luego la toma de tiempos se vuelve a iniciar de manera normal, es decir presionando una vez el botón y luego esperando la señal de largada.

Uso del programa
Descripción general
El programa es realmente muy sencillo de utilizar y se ha hecho hincapié en este punto para que sea intuitivo de moverse entre los distintos menús y secciones. Para ello se consideró la división en pestañas: Home, Entrenamientos, Competencias, Nadadores, Configuraciones y About (ver recuadro rojo en la imagen).

El sistema posee una base de datos para organizar y proteger los tiempos adquiridos. Para ello se lleva automáticamente un registro de los nadadores, sus entrenamientos y las competencias donde participan. Luego de adquiridos los tiempos, los mismos pueden ser fácilmente accedidos a través de los menús para su impresión en papel o simplemente para una consultarlos.

NADADORES
Agregar un nadador
Para realizar la siguiente operación existen dos opciones que conducen al mismo resultado:
- desde la página Home hacer click en el botón que dice Nadadores
- desde cualquier página hacer click en la pestaña Nadadores (extremo superior derecho)
Luego de utilizar cualquiera de las dos alternativas nos encontraremos con una pantalla como la que se muestra a continuación:

Una vez ahí hacer click en el link Agregar nadador ubicado en el extremo inferior izquierdo del cuerpo de la página (ver recuadro rojo en la imagen).

Luego de ello nos encontraremos con una página como la siguiente:

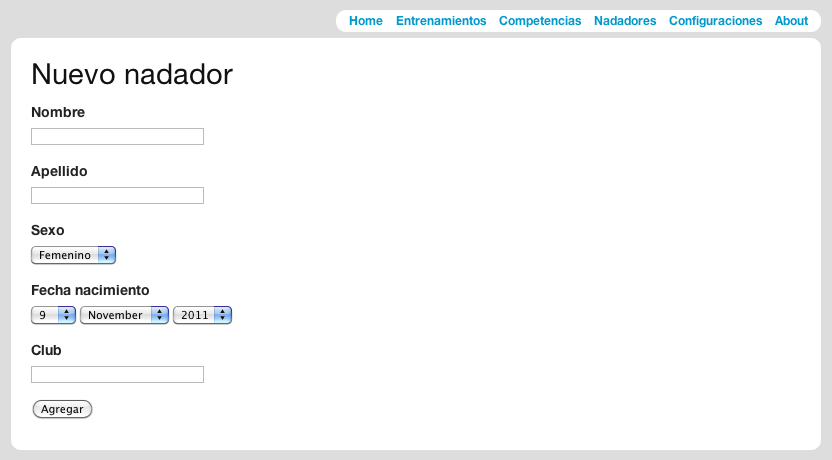
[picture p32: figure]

Dicho formulario debe ser completado con los datos del nadador y luego hacer click en el botón Agregar.
¡Listo!, ya agregamos nuestro primer nadador, ahora deberíamos volver a la primera página automáticamente. Si quisiéramos agregar otro nadador simplemente deberíamos volver a repetir los sencillos pasos anteriores.

Ver nadadores
Esta opción es útil cuando queremos consultar que nadadores están ingresados y queremos consultar algún dato en particular de ellos.
Para poder visualizar los nadadores que se encuentran en la base de datos debemos ir a la página de inicio de los nadadores, para ellos haremos click en el link llamado “Nadadores” en el extremo superior derecho (existe otro método alternativo que fue explicado en el subtitulo anterior: Agregar un nadador) y veremos una pantalla como la que ya se vio al agregar una nadador:

En dicha pantalla haremos click en el link Ver/Modificar nadadores (ver recuadro rojo).

Ahora estaremos viendo una tabla donde las columnas son Nombre, Apellido y los otros datos que fueron ingresados al agregar al nadador.

En el extremo inferior izquierdo existe un link para agregar un nadador para facilitar la tarea cuando se consulta la base de datos.

Editar un nadador
Probablemente Ud. mismo ya haya descubierto como editar un nadador. Sin embargo si prefiere hacer las cosas de la manera correcta aquí encontrará paso a paso como realizar dicha tarea.
Una vez ubicados en la lista de los nadadores a la que se accede haciendo click en el link “Ver/Modificar nadadores” debería ver que en lado derecho del cuerpo de la página existe un link llamado “editar” por cada nadador (ver recuadro rojo).

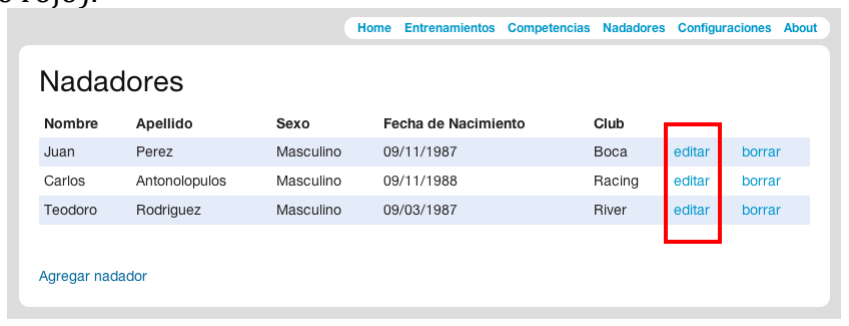
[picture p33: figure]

Cada uno de estos enlaces nos direcciona a una página que permite alterar los registros en la base de datos. Para editarlos solo debe seleccionarlos con el mouse y reescribirlos. Cuando termine debe apretar el botón inferior llamado Actualizar (ver recuadro rojo en la siguiente imagen) para que los cambios sean actualizados en la base de datos.

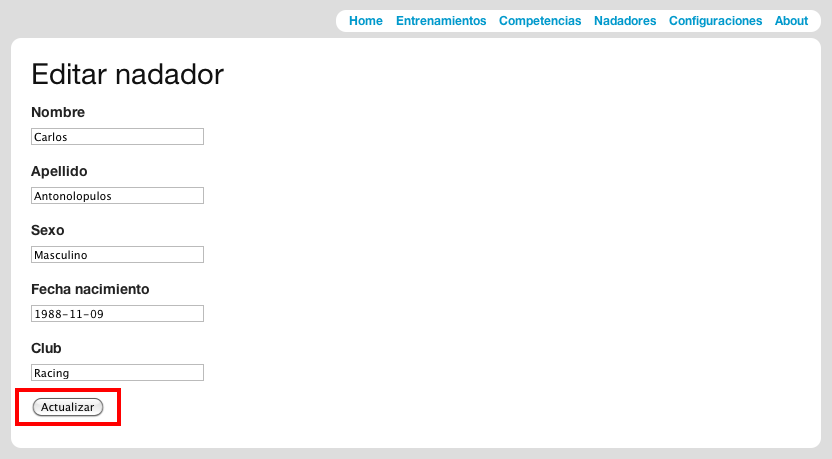
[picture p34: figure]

Luego de oprimir el botón Actualizar nos redireccionaremos automáticamente en la página que lista los nadadores.

Borrar un nadador

Partiendo de la página que lista los nadadores de la base de datos haremos click sobre el link llamado borrar (ver recuadro rojo en la siguiente imagen) que pertenece al nadador que queremos eliminar de la base de datos.

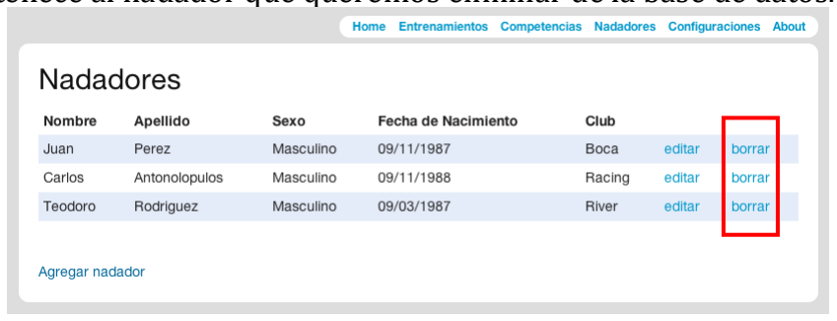
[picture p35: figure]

Luego de hacer click en el link nos aparecerá un cartel de confirmación (ver siguiente imagen). Hacemos click en OK en caso de querer borrar, en cambio si tocamos el botón por accidente clickeamos en Cancel.

ATENCION: borrar un nadador conlleva la pérdida permanente

de sus entrenamientos asociados. Asegúrese de que necesita

borrar un nadador antes de continuar.

ENTRENAMIENTOS
Descripción general
La herramienta entrenamiento es muy útil para hacer pruebas con los deportistas, ya que nos permite guardar un registro ordenado cronológicamente de las marcas que ha hecho un nadador a los largo de ciclos de preparación física.
Se entiende por entrenamiento el tiempo que tardo un nadador en cubrir una determinada distancia empleando para ello un estilo de nado en particular (crawl, pecho, etc). Alguno de estos elementos se seleccionan al crear un nuevo entrenamiento (nadador, estilo de nado, distancia), mientras que el tiempo es adquirido por el sistema en si mismo (cuando el nadador toca la placa de toque o se presiona el pulsador manual).

Agregar un entrenamiento
Agregar un entrenamiento es tan sencillo como crear un nadador. Para ello no dirigimos a la página Entrenamientos, lo cual se puede hacer de dos formas:
- desde la página Home hacer click en el botón llamado Entrenamientos
- desde cualquier página hacer click en la pestaña Entrenamientos (extremo superior derecho)
Luego nos encontraremos con una página como la siguiente:

En dicha pantalla iremos al link “Nuevo entrenamiento” ubicado en el cuerpo de la página (ver recuadro rojo).

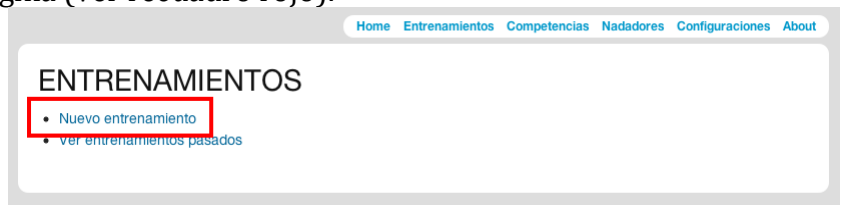
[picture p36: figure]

Lo cual nos llevará a una página como la que se muestra en la siguiente figura:

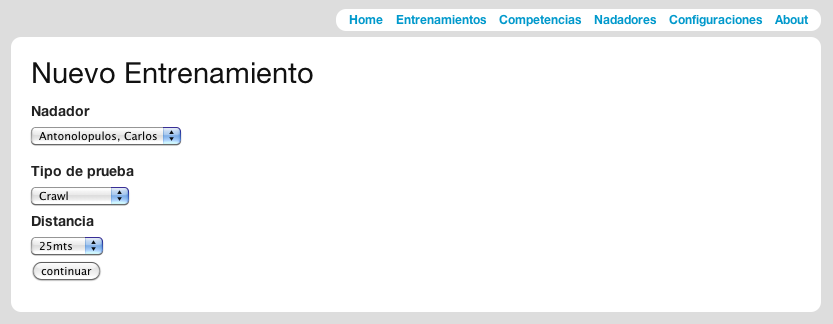
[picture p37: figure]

Aquí lo que debemos hacer es seleccionar el nadador que realizará el entrenamiento, el tipo de prueba, y la distancia. Luego hacemos click en el botón llamado continuar y nos redireccionará automáticamente a la página de adquisición de tiempos.

Adquisición de tiempos
La página de adquisición está dedicada a monitorear el tiempo que va transcurriendo entre que se dio la señal de largada y que el nadador toca la placa de toque o que el juez o un asistente presiona el pulsador correspondiente al carril 1.
Veamos una imagen de dicha pantalla:

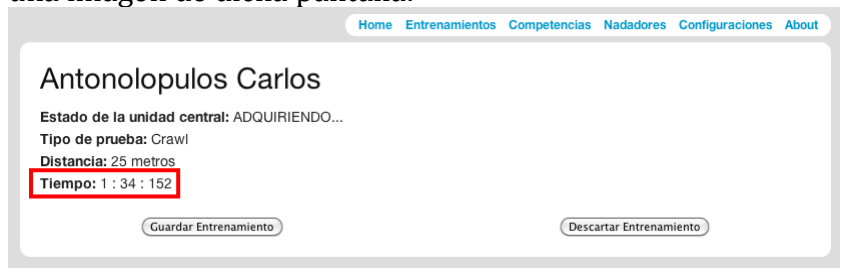
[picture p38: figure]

En la misma se pueden apreciar varias cosas. La primera es que el título de la misma corresponde al nadador que está realizando el entrenamiento. También se puede observar que figuran los campos tipo de prueba y distancia, que son los mismos que seleccionamos en la página anterior. Sin embargo lo más interesante es que los campos estado de la unidad central y tiempo son dinámicos. Es decir estos dos últimos campos se refrescan periódicamente (cada 1 segundo aproximadamente), de forma tal que reflejen que acción está realizando la unidad central y que tiempos está midiendo.
Seguramente el campo que más le importe es el de tiempo (ver recuadro rojo). El mismo se actualizará hasta que la toma de tiempos finalice con la señal que envía la placa de toque o el pulsador manual. Cuando esto suceda uno tendrá la opción de descartar el entrenamiento presionando el botón Descartar Entrenamiento porque tal vez Ud. se encuentre realizando una prueba y no necesite disponer de los datos más adelante. Sin embargo siempre tiene la opción de guardarlos presionando el otro botón llamado Guardar Entrenamiento.
Cualquiera sea el camino elegido terminará redirigido a la página inicial de entrenamientos, sin embargo lo que si cambiará será un cartel que aparecerá cada vez que Ud. realice una de esas dos acciones. Si un entrenamiento fue descartado, entonces se encontrará con una pantalla como la siguiente luego de confirmar que quería descartarlo:

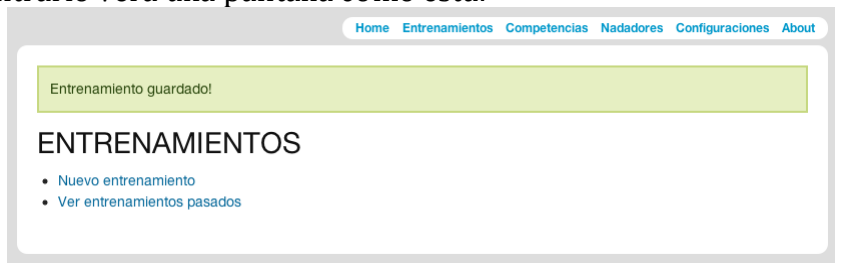
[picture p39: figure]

Caso contrario verá una pantalla como esta:

Ver un entrenamiento
Para ver un entrenamiento en particular debemos presionar el link “Ver entrenamientos pasados” (ver siguiente imagen) en la página inicial de entrenamientos.

Esto nos llevará a una página en la cual debemos seleccionar el nadador.

Luego de seleccionar el nadador solo debemos presionar el único botón llamado “continuar” para poder acceder al listado de entrenamientos de ese nadador en particular. Este listado aparecerá por orden cronológico como se muestra a continuación:

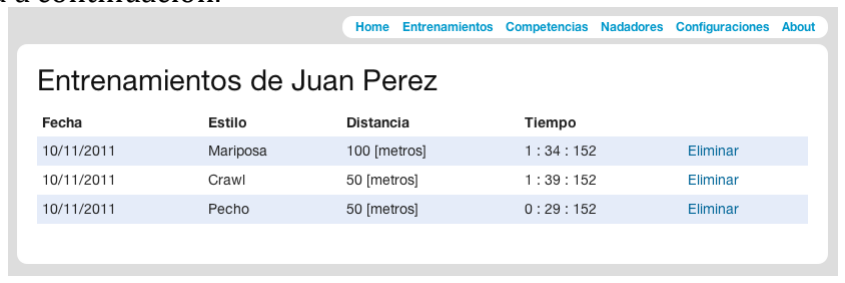
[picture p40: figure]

Borrar un entrenamiento

Borrar o eliminar un entrenamiento es tan sencillo como borrar un nadador. Primero debemos acceder a los entrenamientos de un nadador en particular (ver sección Ver un entrenamiento) y luego hacer click en el link que aparece a la derecha de la página.
Cada link corresponde al entrenamiento de la línea en la que se encuentra, de modo tal que si quisiéramos borrar el entrenamiento en el que Juan Perez nado estilo 50 metros en estilo crawl debemos clickear sobre el link “Eliminar” que se muestra en la próxima figura.

ADVERTENCIA: borrar un entrenamiento conlleva la pérdida

permanente de los tiempos adquiridos. Asegúrese que necesita

borrar un entrenamiento antes de continuar.

Al igual que antes, siempre que queramos borrar un dato se nos pedirá confirmación con un cartel como el siguiente:

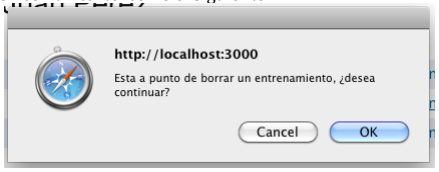
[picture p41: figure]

Luego de confirmar se nos redirigirá automáticamente a la página inicial de entrenamientos con un cartel que indicará que se borrado exitosamente el entrenamiento (ver siguiente imagen).

COMPETENCIAS
Descripción general
La herramienta competencia está pensada para organizar los tiempos realizados un evento deportivo, de forma tal que puedan ser accedidos para su visualización en fechas posteriores a la competencia y durante la misma. Una competencia está formada por partidas, y estas a su vez por dos o más nadadores.

Agregar una competencia
Agregar una competencia es realmente sencillo y consta de unos pocos pasos. En primer lugar Ud. debe ir a la página de inicio de Competencias, esto puede ser realizado de dos maneras:
- desde la página Home hacer click en el botón llamado Competencias
- desde cualquier página hacer click en la pestaña Competencias (extremo superior derecho)
Ahora debería ver una pantalla como la siguiente:

En esta pantalla debería hacer click en el link “Agregar competencia” (ver recuadro dentro de la imagen).

Esta última acción nos llevará a la siguiente página, la cual deberá ser completada con los datos solicitados (Nombre del evento y Fecha del evento) y luego se deberá presionar el botón guardar.

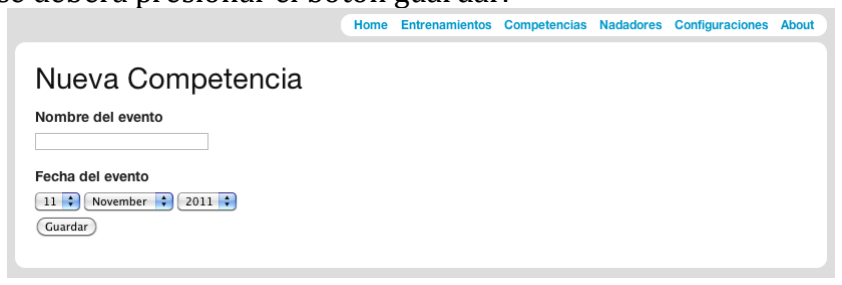
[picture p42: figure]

Al apretar el botón “Guardar” la página nos redirigirá automáticamente a la página de inicio de la competencia creada. Esa pantalla se verá como la siguiente imagen.

Ahora tan solo resta ir agregando las partidas a medida que se vayan sucediendo las mismas en la pileta para poder adquirir los tiempos de los nadadores (ver la sección partidas).

Ver una competencia
Para acceder a una competencia y ver los tiempos que se han registrado en sus partidas debemos dirigirnos a la vista del evento en cuestión. Para ello iremos a la página inicial de competencias con cualquiera de los dos métodos visto en la sección “Agregar una competencia).
Una vez ubicados en dicha página deberemos hacer click en el link llamado “Ver competencias” (ver recuadro en la siguiente imagen).

Al hacer click en el link mencionado, nos dirigiremos a una pantalla que muestra todas las competencias que fueron agregadas en el pasado y por orden cronológico. Se debería ver algo como lo siguiente:

Esta página es llamada index de competencias y le recomendamos que intente recordarlo pues será mencionado en los títulos “Editar una competencia” y “Borrar una competencia”.

Ahora debemos hacer click en el nombre de la competencia que queremos visualizar (en este ejemplo será “Promocionales UTN”), lo cual nos redireccionará una página de inicio de la competencia como la que se muestra a continuación.

Se puede apreciar que no se registran partidas pues la competencia recién fue creada y así se comportará el programa cada vez que se cree una nueva competencia.
También se puede ver que existe un link para agregar partidas, el cual se explicará en el inciso “Agregar una partida”.

Editar una competencia
La edición de las competencias esta pensado para aquellos casos en los que por un error se tipeo mal el nombre del evento o se ingresó mal la fecha del mismo. En ningún caso se podrán modificar los datos adquiridos desde la unidad central.
Para la edición de una competencia partiremos de la página llamada index de competencias. En la misma se puede observar que hay una columna que contiene links bajo el nombre de “editar” (ver recuadro en la siguiente imagen).

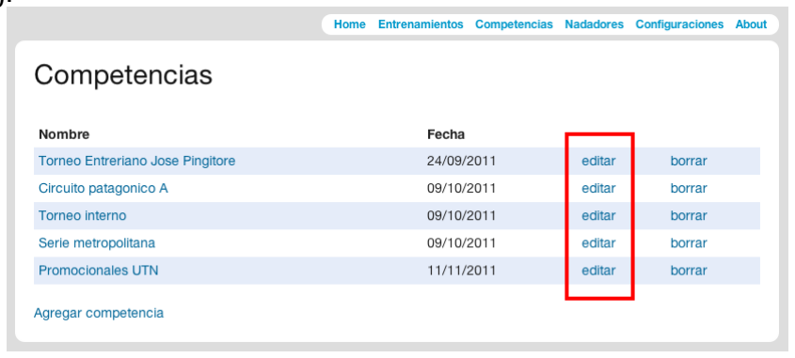
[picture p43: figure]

Al hacer click sobre el link correspondiente al evento que queremos editar nos encontraremos con una página como la siguiente. En la cual solo debemos corregir los campos deseados y luego hacer click en el botón “Actualizar”.

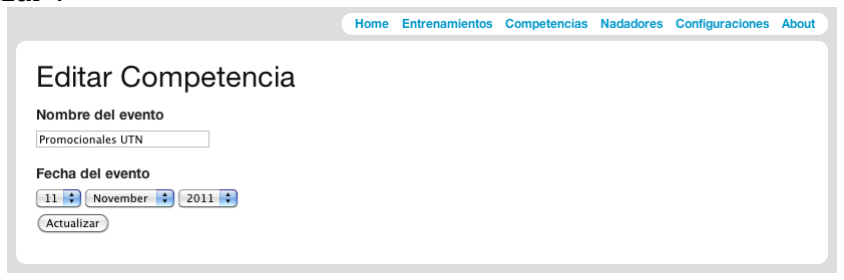
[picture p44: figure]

Borrar una competencia

Borrar una competencia consta de muy pocos pasos y es tan intuitivo como fue borrar un nadador o un entrenamiento.
Partiendo de la vista index de competencias debemos buscar el link que se llama borrar correspondiente a la competencia que deseamos eliminar (ver imagen siguiente).

ADVERTENCIA: borrar una competencia conlleva la pérdida de

sus partidas asociadas de forma permanente. Asegúrese de que

Ud. necesita borrar una competencia antes de proseguir con

esta acción.

Luego hacemos click en el link deseado y nos aparecerá una cartel como el siguiente:

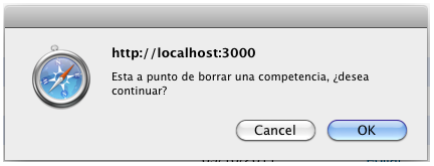
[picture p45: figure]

Presionamos “OK” para confirmar que queremos borrar y la página se actualizará automáticamente mostrando el cambio realizado.
Si en cambio presionamos el link por accidente, solo debemos apretar “Cancel” para deshacer la acción y que no se borre la competencia. La página se mantendrá sin cambios.

Agregar una partida
La creación de partidas es un paso necesario para la adquisición de tiempos durante una competencia.
Para crear una partida debemos posicionarnos en la página de inicio de la competencia (ver el titulo “Ver una competencia”) como se muestra a continuación

En la misma imagen se puede apreciar un link llamado “Agregar partida” el cual nos guiará a la siguiente página para que nosotros podamos elegir, la distancia a nadar, el tipo de prueba (crawl, pecho, etc) y los dos o más nadadores. Cabe hacer dos aclaración en este punto:
- el operador debería seleccionar dos o más nadadores, sin embargo por un descuido puede suceder que seleccione un solo nadador. El programa no advertirá el error y por lo tanto el tiempo adquirido en el otro andarivel se registrará pero no se mostrará al ver los resultados de una partida. Ud. debe prestar especial atención al momento de seleccionar los nadadores por carril. En caso de error elimine la partida y vuelva a programarla

- Si un nadador es seleccionado en 2 o más andariveles no será advertido por el programa. En este caso los tiempos se registrarán pero solo dependerá de Ud. saber que nadador nado en que carril. Recomendamos borrar la partida y volverla a programar en caso de advertir este error. Luego de presionar sobre el link “Agregar partida” nos encontraremos con una página como la siguiente:

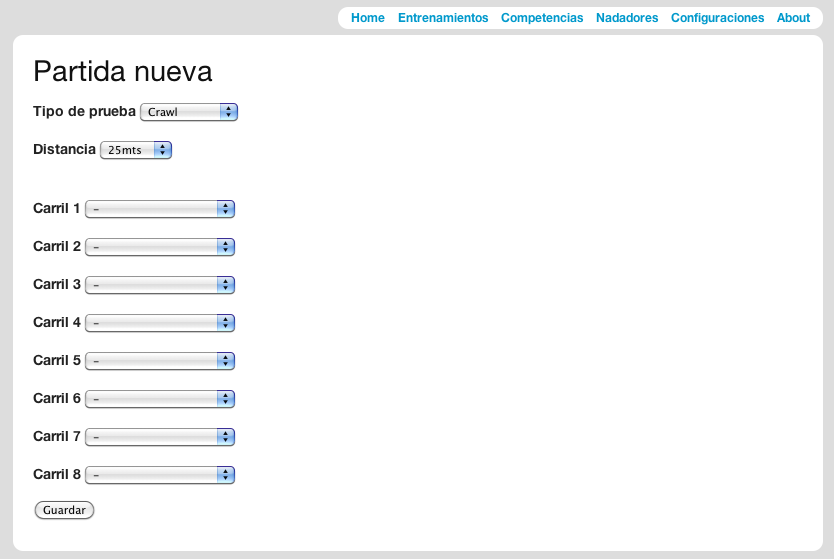
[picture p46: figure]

En la misma debemos ingresar los valores solicitados y luego presionar el botón “Guardar”, lo cual nos redireccionará a la página inicial de la competencia observándose en la misma que ahora se muestra una partida que anteriormente no estaba.

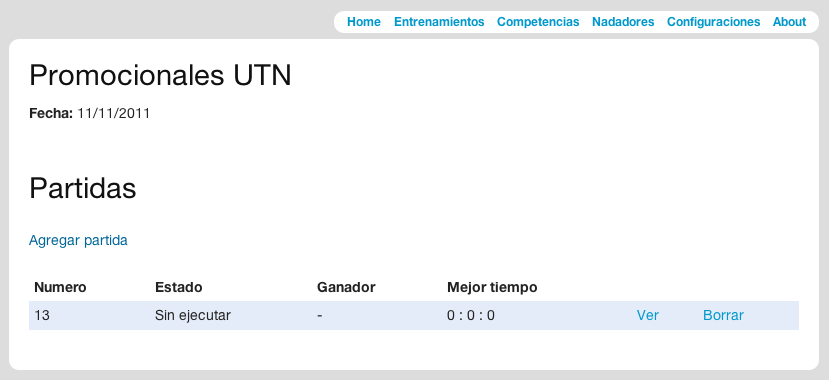
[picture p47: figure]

Veamos con un poco más de detenimiento la pantalla. En primer lugar vemos que una columna se llama “Numero”. Esta columna siempre mostrará un número único para la partida que no se repetirá en ninguna otra competencia. Este número nos permitirá identificar la partida en caso de querer referirnos a ella en planillas manuales.
También tenemos la columna llamada Estado, y nos indica si la partida se encuentra “Sin ejecutar” (todavía no se adquirieron los tiempos) o “Ejecutada” (los tiempos ya fueron adquiridos).
Por otro lado se muestra quien fue el ganador en dicha partida en formato “Apellido, Nombre” y el tiempo que hizo dicho nadador en la columna Mejor tiempo. En caso de encontrarse una partida en estado “Sin ejecutar” esta columna mostrará el tiempo en 0 : 0 : 0.
También se muestran dos columnas más con links, en una se muestran los links para ver las partidas y en otra se muestran los links para borrar partidas. Cada una de estas columnas serán analizadas en los títulos “Adquisición de tiempos” y “Borrar una partida” respectivamente.

Adquisición de tiempos
La adquisición de tiempos es el paso intermedio entre la base de datos y la unidad central, por eso es muy importante que preste mucha atención en las siguientes líneas para realizarlo de forma correcta.
Para adquirir tiempos partiremos de la página inicial de la competencia en cuestión (asumiendo que ya se creó la partida) y haremos click en el link “Ver” de la partida que queremos ejecutar (ver siguiente imagen). Si la partida acusara el estado

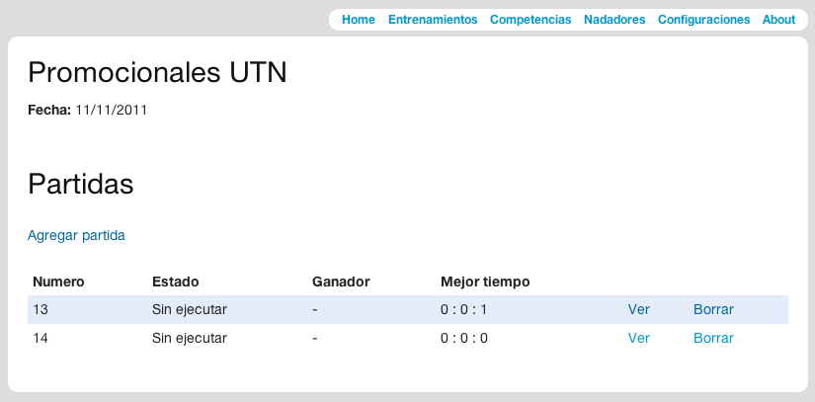
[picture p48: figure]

Luego nos encontraremos con una vista como la siguiente:

En esta página se puede apreciar que la primera línea: Estado de la unidad central. Dicha línea puede mostrar tres valores distintos a saber:
- ADQUIRIENDO…: aparecerá cuando la unidad central este adquiriendo datos o que este lista para que el juez de competencia de la señal de largada con su pulsador manual.
- PARTIDA EN FALSO: esta leyenda aparecerá cuando se presione el botón de la unidad central. Indica que la partida fue anulada y deberá reiniciarse por lo que se ponen los cronómetros a cero.
- FINALIZADO: esta leyenda aparecerá cada vez que todos los nadadores hayan finalizado la prueba, es decir cuando hayan tocado la placa de toque o se haya presionado el pulsador manual.
Ahora solo resta esperar a que los nadadores terminen la prueba y aparezca la leyenda FINALIZADO. Solo cuando esto ocurra Ud. podrá abandonar la página. Caso contrario comprometerá la adquisición de los tiempos para guardarlos en la base de datos.

Ver una partida
Para ver una partida que ya ha sido ejecutada debe dirigirse a la página inicial de la competencia donde tuvo lugar dicha partida. En nuestro caso se verá así:

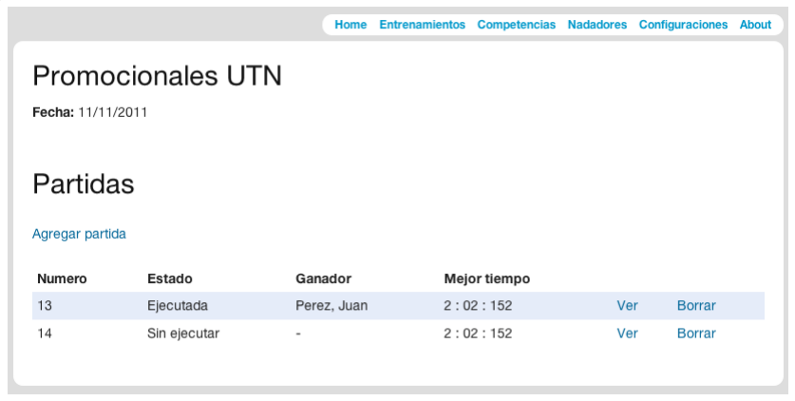
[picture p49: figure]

Luego debe hacer click en el link “Ver” para dirigirse a la página que le mostrará la partida ejecutada. Esa partida se verá de la siguiente manera:

En este caso se puede apreciar que la primera línea luego del título cambió, ahora se aprecia “Partida ejecutada”. Es decir, lo mismo que se podía apreciar en la página inicial de la competencia. Esto quiere decir que por más que la unidad central este adquiriendo datos, los mismos no serán asociados a la partida que estamos visualizando. Sin embargo insistimos con el consejo de no abandonar la página mientras el estado de la unidad central figure en la misma y se pueda leer “ADQUIRIENDO…”.

Borrar una partida

Borrar una partida es algo muy sencillo de realizar. En primer lugar Ud. debe saber que tiene dos caminos para realizar esta acción:
- desde la página inicial de la competencia

ADVERTENCIA: borrar una partida conlleva la pérdida

permanente de los tiempos adquiridos en la misma. Asegúrese

que necesita borrar una partida antes de continuar con esta

acción.

- desde la página de la partida que se desea borrar
Veamos el primer caso, es decir partiendo desde la página inicial de la competencia donde tuvo lugar la partida.
Desde esta página podemos apreciar que la última columna (empezando de izquierda a derecha) posee links llamados “Borrar” (ver recuadro en la siguiente imagen). Cada link corresponde a la partida que se encuentra en la misma línea.

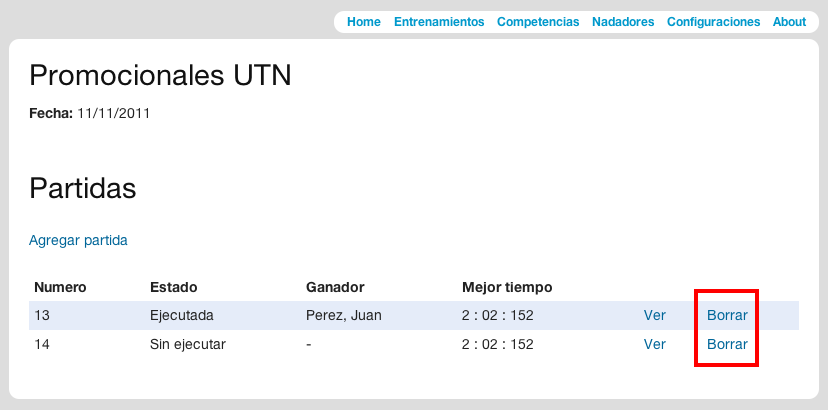
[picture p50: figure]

Si hacemos click sobre un link nos aparecerá un cartel como el de la siguiente imagen. Si queremos proceder y borrar la partida presionamos “OK”, caso contrario presionamos “Cancel”.

Luego de borrar una partida nos encontraremos con una pantalla como la siguiente, en la cual aparece un recuadro en la parte superior de la pantalla que la partida fue borrada.


Mantenimiento y cuidados del sistema
Placas de toque
Las placas de toque no deben ser dejadas en el agua permanentemente. Se recomienda instalarlas unas horas antes de la competencia (o entrenamiento) y retirarlas al finalizar la misma para disminuir la exposición ante agentes corrosivos. Asimismo se recomienda guardarlas en un lugar seco una vez que se hayan secado completamente luego de su uso.
Los puntos a inspeccionar en las placas de toque son:
- Sus fundas en busca de desgastes o agujeros que comprometan su impermeabilidad.
- Los contactos de las mismas en busca de oxido.
- Los cables deben ser probados como se indica en la sección “Cables y Conectores”.
Ante la detección de algún inconveniente que pudiera poner en riesgo la integridad del equipo o de su correcto funcionamiento contactarse con su vendedor para conseguir un diagnóstico más preciso y en caso de necesitarlo recambiar algún componente.

Unidad central
La unidad central posee electrónica que es sensible al agua como cualquier dispositivo. El mismo no debe ser mojado, ni se debe encontrar en un lugar tal que pueda ser mojado o salpicado. En caso de mojarse haberse mojado severamente póngase en contacto con su vendedor.
El equipo debe ser guardado en un lugar seco. No recomendamos que quede en un cuarto de mandos de la pileta pues ese lugar suele tener bastante cloro en el ambiente.
Recomendamos guardar el equipo dentro de un lugar seco y ventilado.

Cables y Conectores
Los cables con sus conectores tal vez sean el elemento al que menos importancia le den los usuarios, esto hace que sea el eslabón más fino en la confiabilidad del sistema, por eso recomendamos enfáticamente que los mismos sean inspeccionados periódicamente si los mismos se encuentran instalados de forma permanente.
La vida útil de los mismos si se encuentran fijos en el natatorio es de unos 2 años. Este periodo puede disminuir si los mismos se encuentran expuestos a los rayos UV.
Los conectores también sufren un deterioro importante por encontrarse tan expuestos como los cables a las condiciones de humedad y cloro.
Los cables deben ser inspeccionados visualmente en busca de cortes o desgastes importantes en su vaina exterior. Al mismo tiempo se deben testear eléctricamente, para lo cual se ha dotado a la unidad central de leds para ver que los cables y conectores están conduciendo eléctricamente. Queremos dejar en claro que si un cable y conector conducen eléctricamente no es motivo suficiente para no ser reemplazado, debido a que los cables puede mostrar signos de deterioro notable y seguir conduciendo. Hacer caso omiso de esto puede derivar en que dejen de funcionar cuando más se los necesite.

Pulsadores manuales
Requieren muy poco mantenimiento, solamente inspeccionarlos antes de ser usados en busca de golpes que comprometan su gabinete plástico.
Evitar impactarlos o dejarlos caer al piso, pues esto puede comprometer la estructura del mismo.
Los cables y conectores deben ser probados como se explico anteriormente en la sección “Cables y Conectores”.

Fallas comunes y soluciones

Problema | Solución
La unidad central no enciende | • verifique que la fuente de alimentación se encuentra conectada a un toma corriente de la pared y que su luz verde se encuentra encendida • verifique que el cable de la fuente de alimentación no se encuentre roto, ni que presente signos de deterioro o esté mal conectado
Placa de toque o pulsador manual no responde | • verifique que la fuente de alimentación este conectada correctamente • verifique que las conexiones de los cinturones de conexión están realizadas correctamente en ambos extremos • verifique el estado de los conectores
La placa de toque y/o el pulsador manual funciona pero las indicación lumínica no funcionan correctamente | • desconecte y vuelva a conectar la fuente de alimentación de la unidad central para reiniciar el equipo
El programa no muestra los datos de la unidad central | • verifique que el cable USB se encuentre conectado correctamente • desconecte y vuelva a conectar la fuente de alimentación de la unidad central para reiniciar el equipo
El programa no guarda los datos correctamente o falla al guardarlos | • comuníquese con el servicio técnico para determinar la causa del problema
La unidad central comienza a adquirir tiempos automáticamente | • verifique que el cable del pulsador de señal de largada está conectado donde debe y que no este invertido con el de la bocina

Si el problema persiste luego de realizar la secuencia de pasos para solucionarlo comuníquese con el servicio técnico para obtener un diagnostico del problema y su posterior reparación.

Especificaciones Técnicas

Unidad Central

Mecánicas
Dimensiones | 28x18x9 cm
Peso | 2Kg
Eléctricas
Alimentación | 12V DC
Consumo | <800mA
Resolución | 0.001 s
Incertidumbre | <0.001% del valor mostrado*
Conexión con PC | USB
(*) Esta incertidumbre garantiza que en mediciones de hasta 10 minutos, el valor de la décima de segundo sea correcto.

Placas de toque

Mecánicas
Dimensiones (Ancho x Alto x Espesor) | 110 x 90 x 3 cm
Peso | 10Kg

Cajas de conexión

Mecánicas
Dimensiones (Ancho x Alto x Espesor) | 15 x15 x 9 cm
Peso | 0,5Kg

Placas de toque

Mecánicas
Dimensiones (Ancho x Alto x Espesor) | 110 x 90 x 3 cm
Peso | 10Kg
Largo de cable | 2mts

Pulsador Manual

Mecánicas
Dimensiones (Ancho x Alto x Espesor) | 16 x3 x2 cm
Peso | 100g
Largo de cable | 2mts

Contacto

Se detallan a continuación las vías de contacto de la empresa.

Teléfono: 011-15-6194-5121
011-15-5499-6824

e-mail: carlosreyes83@gmail.com emmanuelponsone@gmail.com

Dirección:

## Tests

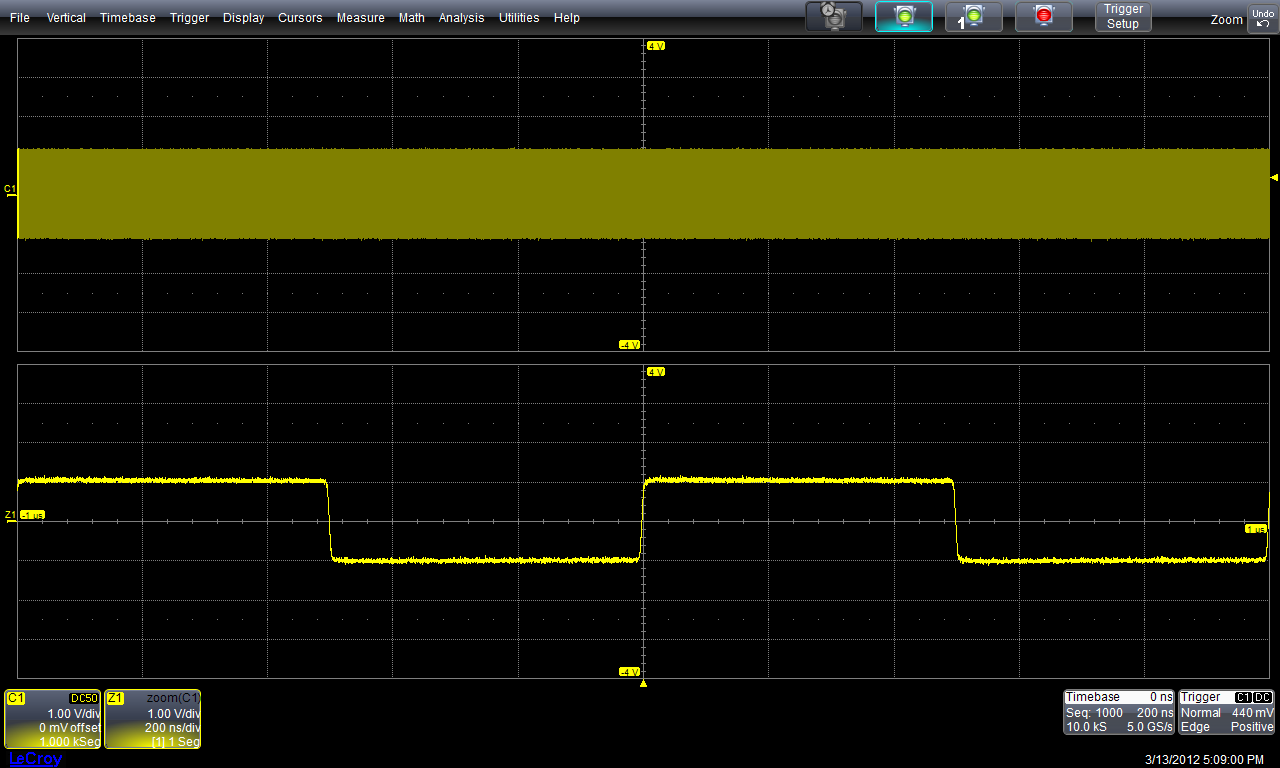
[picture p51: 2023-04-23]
00 - Cable delay measurements/pulso 1mhz limpio.png

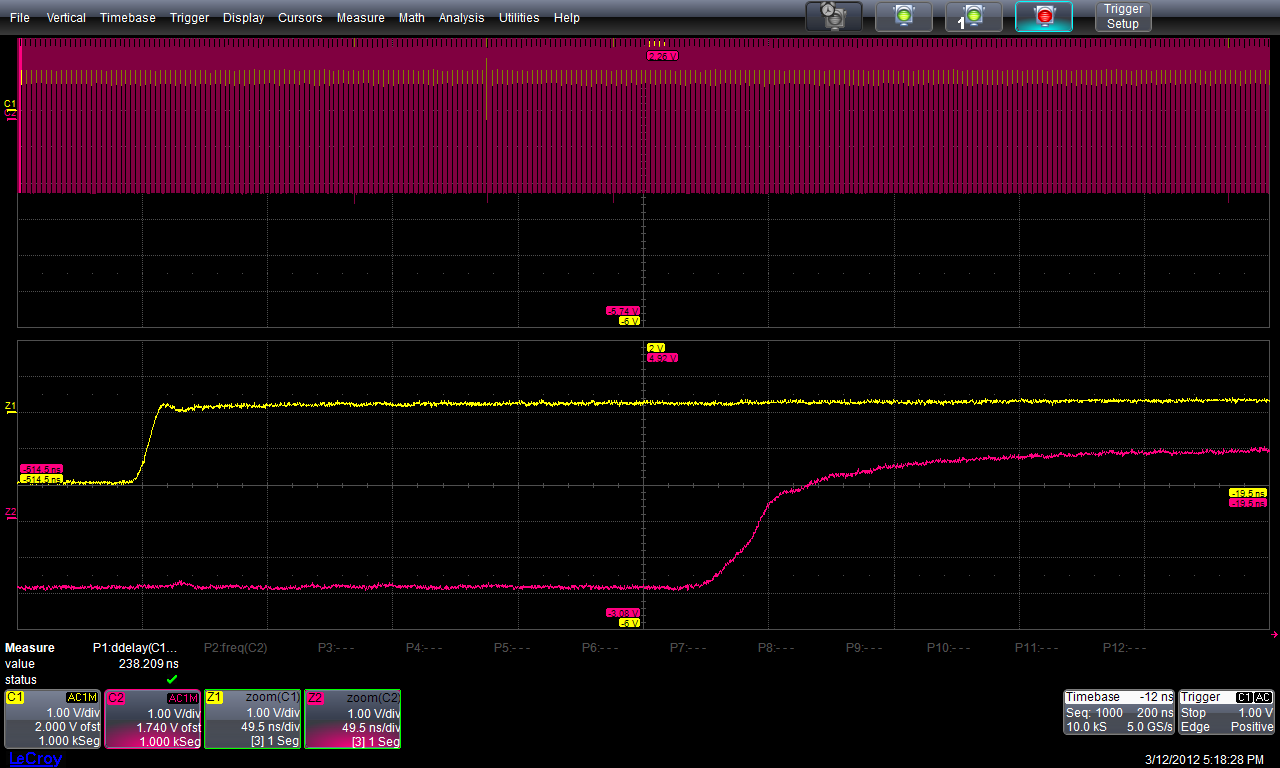
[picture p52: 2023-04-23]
00 - Cable delay measurements/retraso cables 1.png

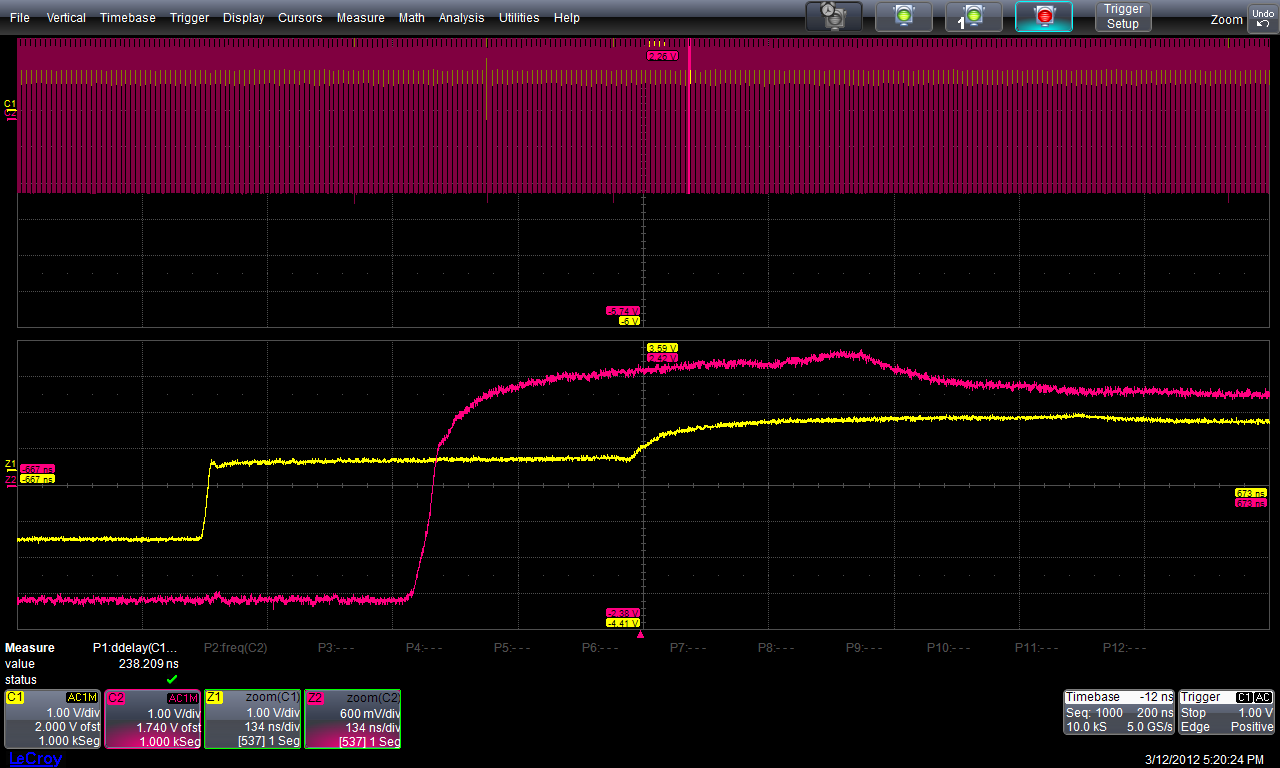
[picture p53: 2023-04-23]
00 - Cable delay measurements/retraso cables 2.png

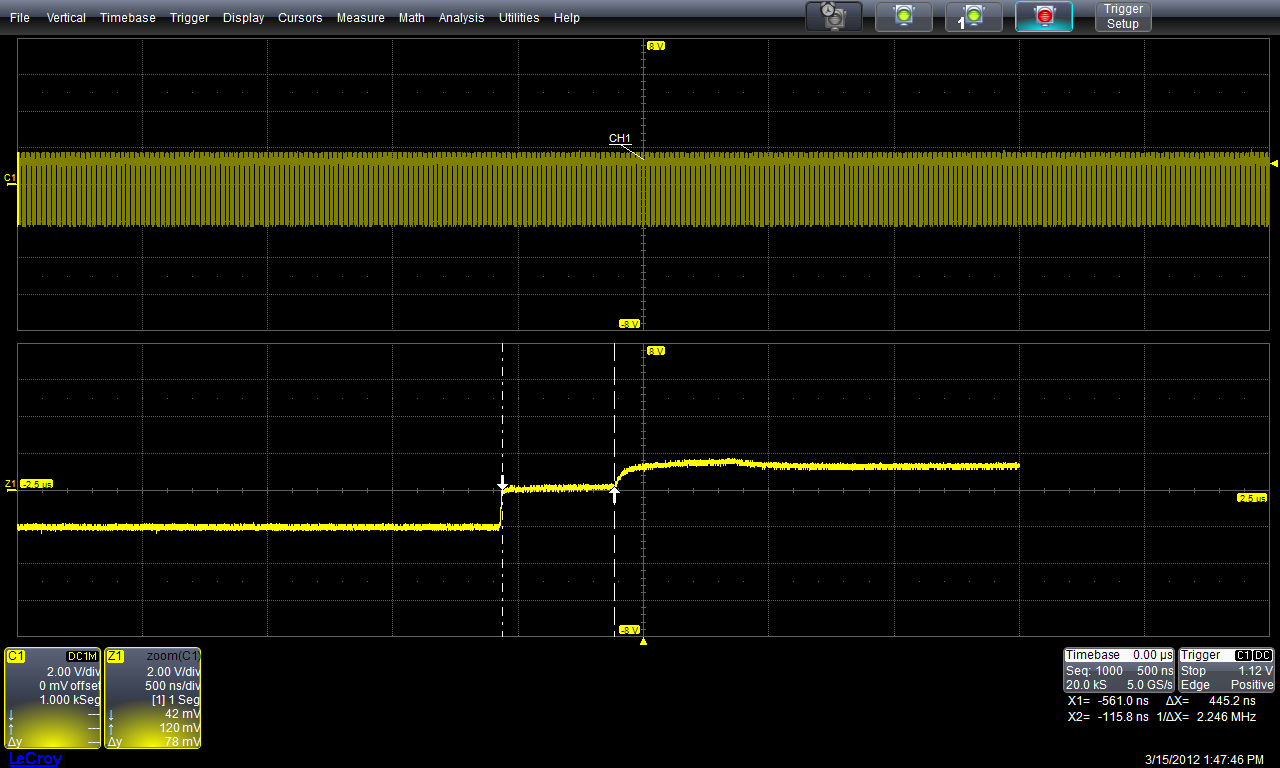
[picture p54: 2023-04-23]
00 - Cable delay measurements/retraso cables 3.png

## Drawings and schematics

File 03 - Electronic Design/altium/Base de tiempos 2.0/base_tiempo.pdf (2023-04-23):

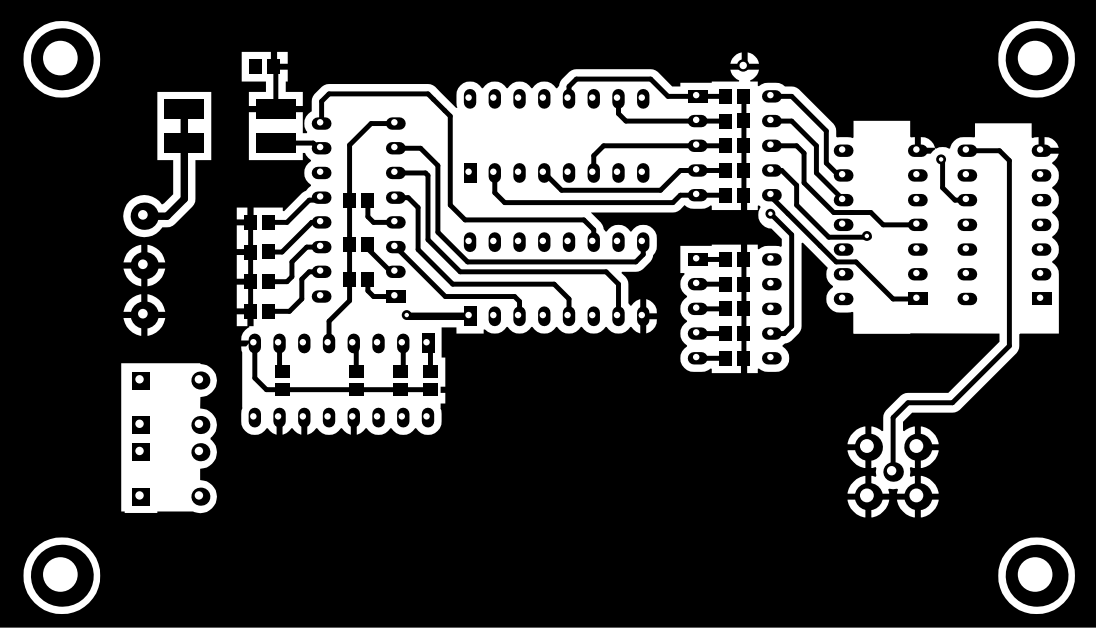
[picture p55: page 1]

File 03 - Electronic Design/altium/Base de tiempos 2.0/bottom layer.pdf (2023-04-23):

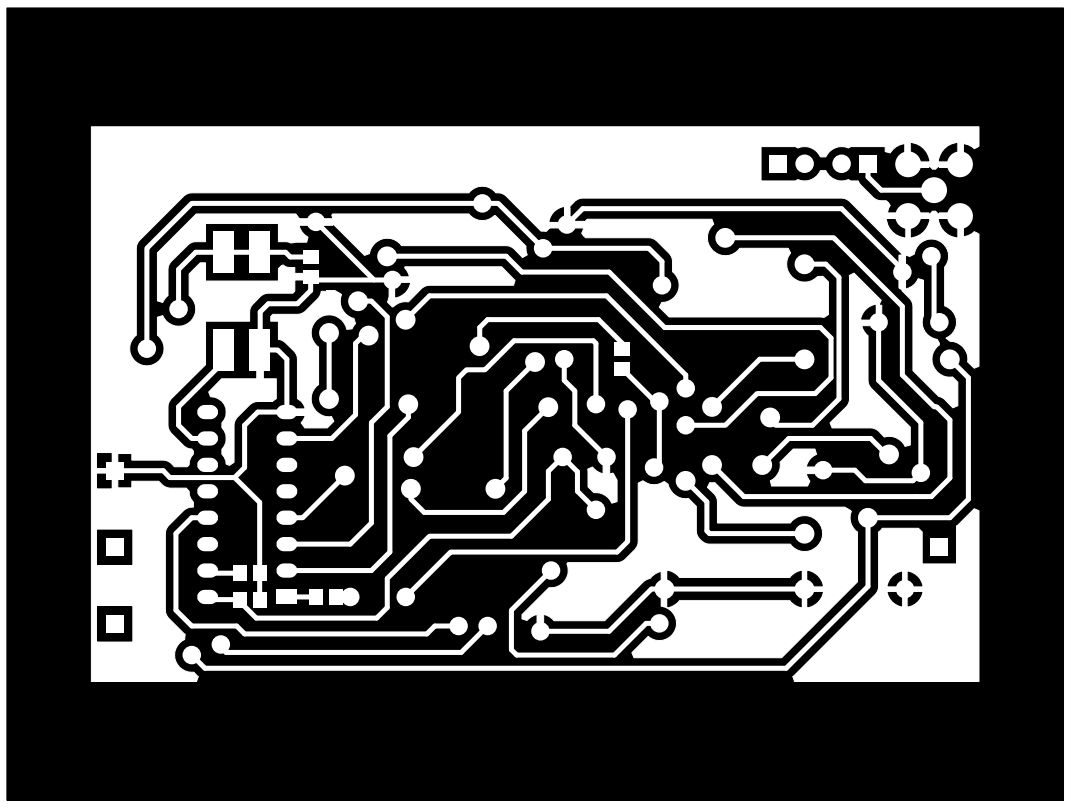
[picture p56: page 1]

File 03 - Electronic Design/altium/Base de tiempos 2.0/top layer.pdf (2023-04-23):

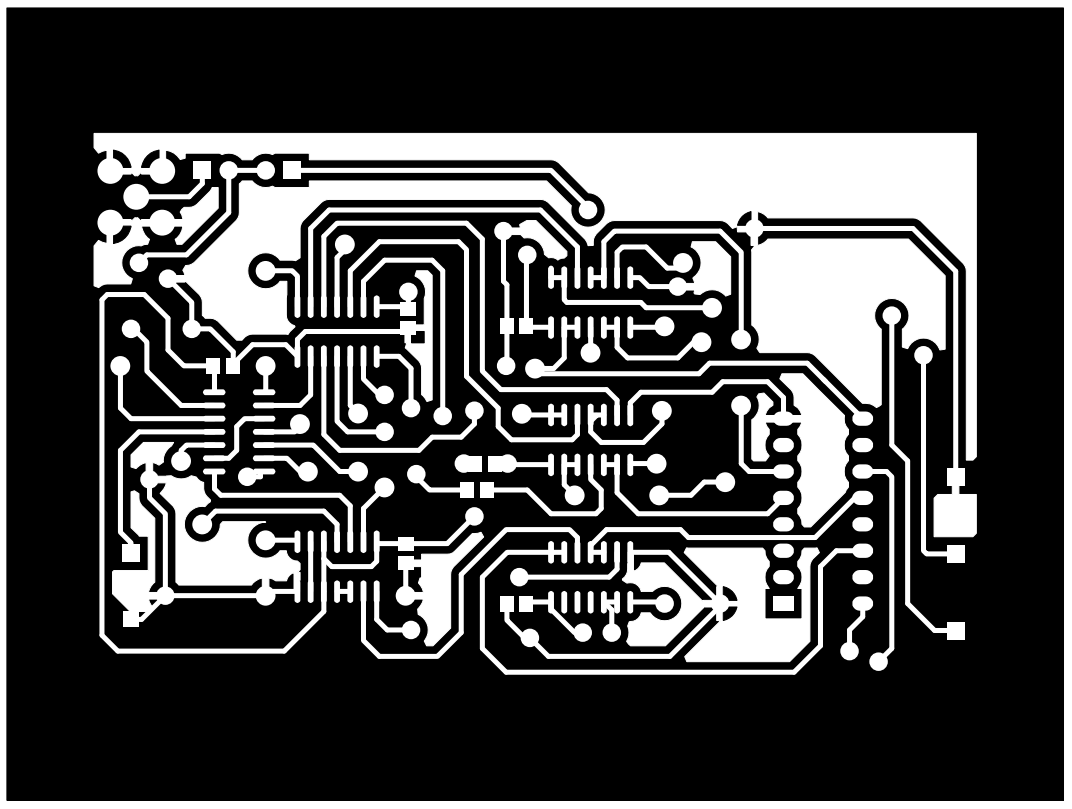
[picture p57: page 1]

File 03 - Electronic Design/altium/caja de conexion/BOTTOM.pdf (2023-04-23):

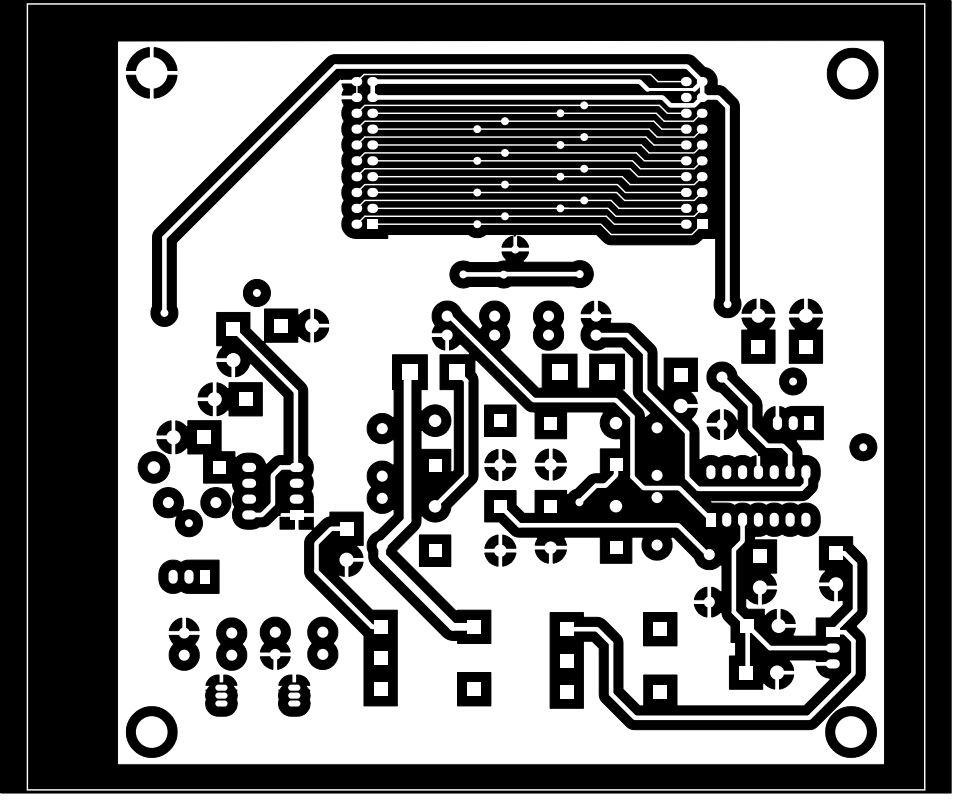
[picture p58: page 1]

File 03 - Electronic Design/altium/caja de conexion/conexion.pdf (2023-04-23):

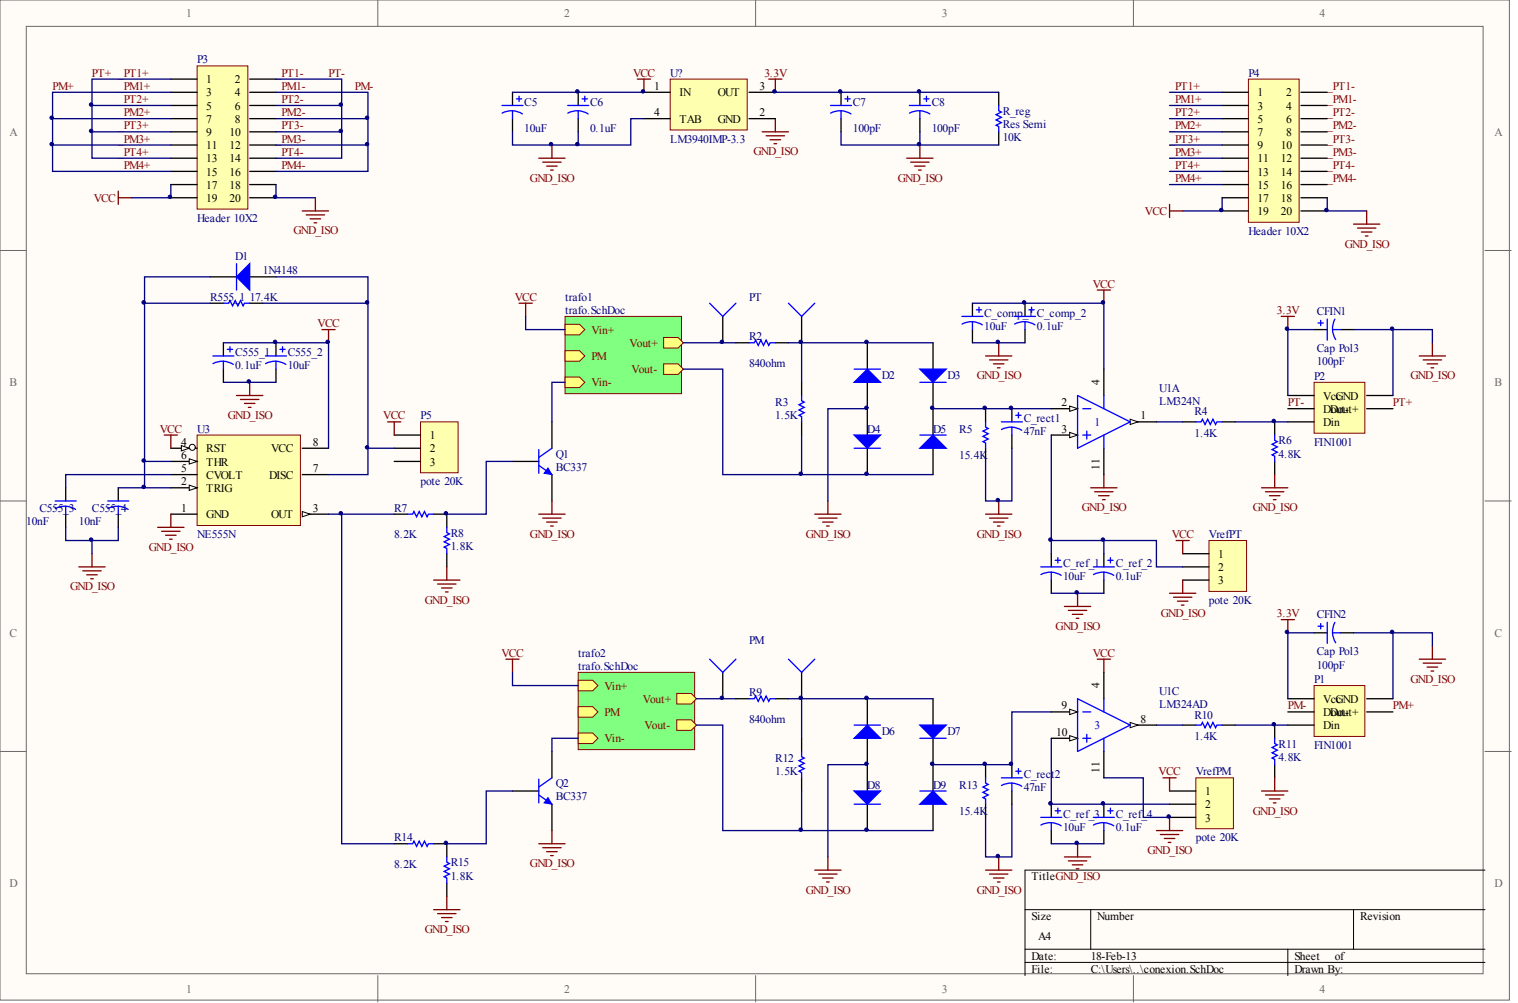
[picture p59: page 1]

Cap Pol3 100pF P2

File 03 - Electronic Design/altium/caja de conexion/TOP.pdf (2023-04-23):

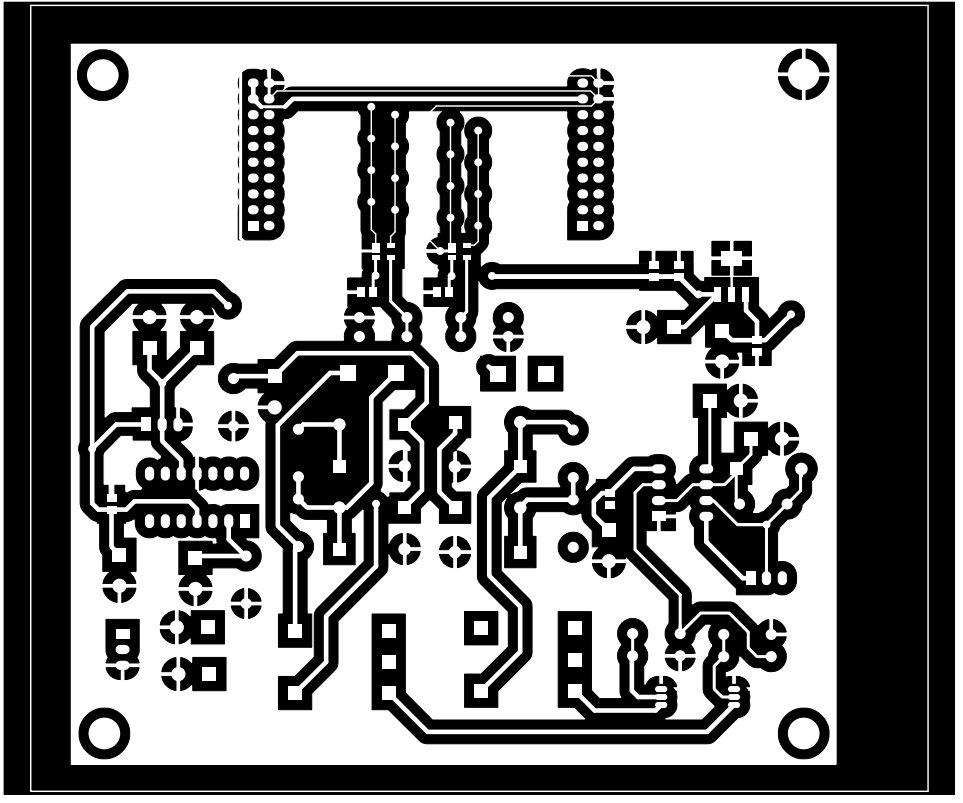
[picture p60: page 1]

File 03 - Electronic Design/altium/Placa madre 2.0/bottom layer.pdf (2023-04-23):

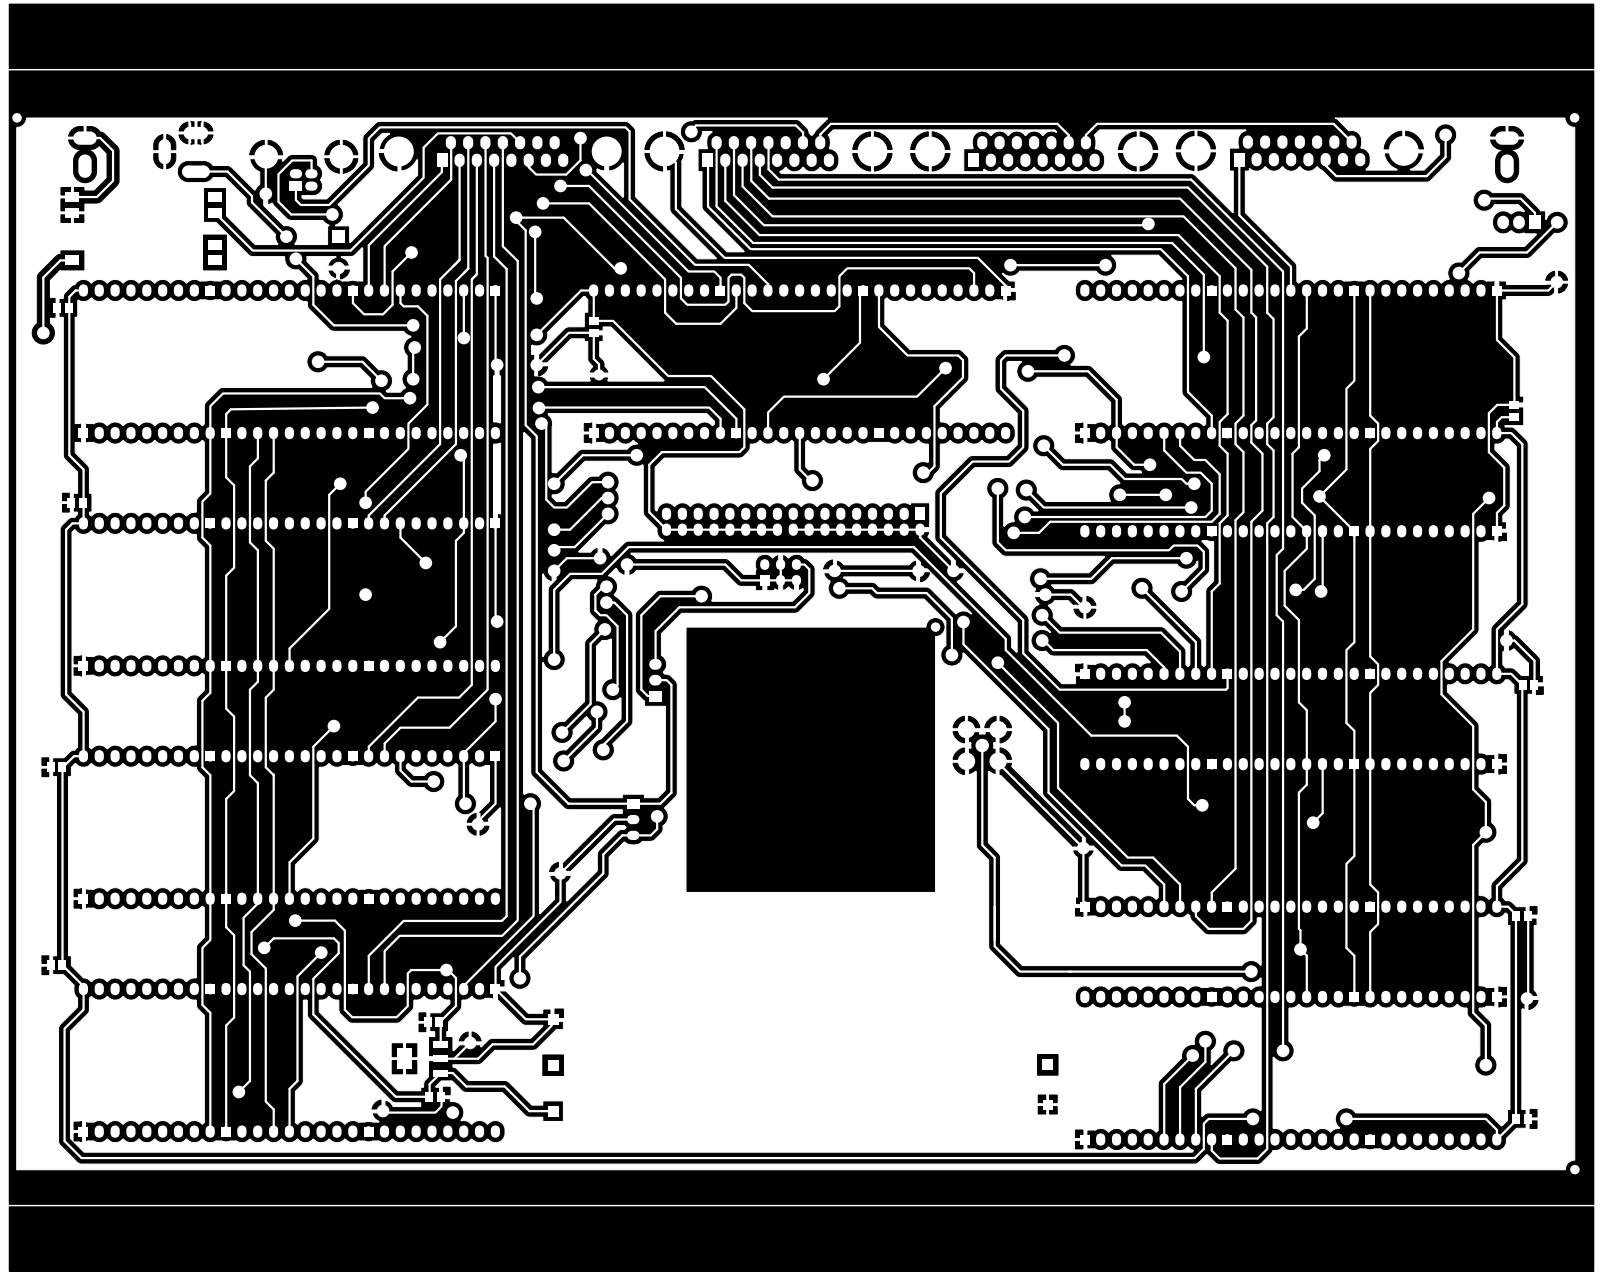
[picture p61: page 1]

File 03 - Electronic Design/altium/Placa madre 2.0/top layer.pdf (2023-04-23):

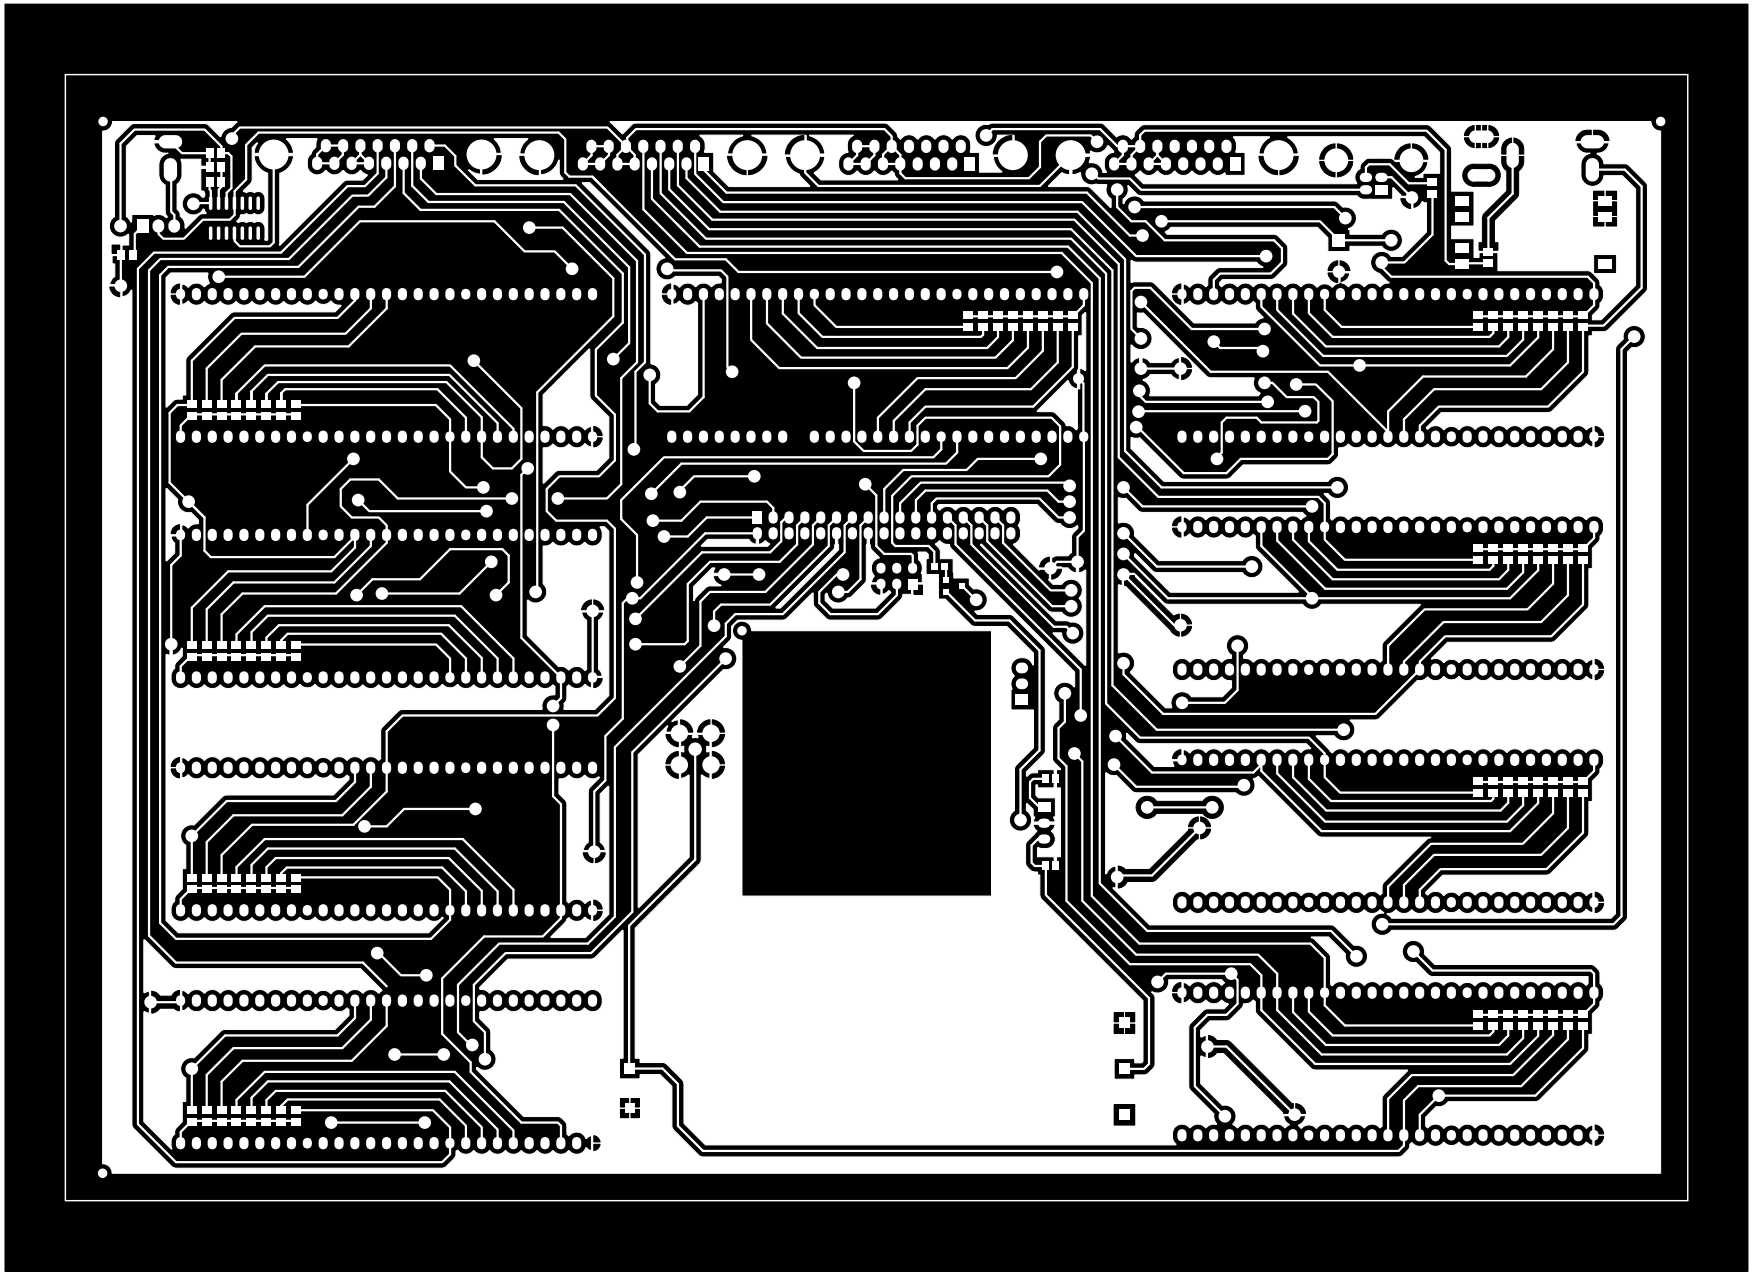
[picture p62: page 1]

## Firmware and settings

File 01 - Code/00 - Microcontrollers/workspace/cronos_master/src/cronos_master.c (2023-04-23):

/*----------------------------------------------------------------------------
 *      Name:   main.c
 *      Purpose: Programa principal para la unidad maestra del sistema cronos
 *      Version: V0.1
 *--------------------------------------------------------------------------*/

#include "LPC13xx.h"
#include "type.h"
#include "usb.h"
#include "usbcfg.h"
#include "usbhw.h"
#include "usbcore.h"
#include "cdc.h"
#include "cdcuser.h"
#include "vcomdemo.h"
#include "string.h"
#include "uart.h"

#include "clkconfig.h"
#include "gpio.h"
#include "config.h"
#include "timer32.h"

#define     EN_TIMER32_1    (1<<10)
#define     EN_IOCON        (1<<16)
#define     EN_USBREG       (1<<14)
#define 	NUM_BYTES		8
#define		OK				1
#define		HAB_OK			2
#define 	NLAPS_OK		3
#define		DESC			0
#define 	VIRGEN			0
#define		PC_OK	 		1
#define		SET	 			2
#define		ADQ	 			3
#define		RESET 			4
#define		FIN 			5
#define		UI_FIN 			0
#define		UI_RUN 			1

extern volatile uint32_t UARTCount;
volatile uint32_t auxiliar,resto;
extern volatile uint8_t UARTBuffer[BUFSIZE];
volatile uint8_t  Buffer[BUFSIZE], estado[8];
unsigned char aux,start,laps,inicializacion,comienzo,hab_andrv[8];
struct DATOS info;
struct TIME tiempos;
union CUENTAS pepe;


union CUENTAS
{
	uint32_t cuenta[1];
	unsigned char bytes[4];

};


struct DATOS
{
unsigned char estado[NUM_BYTES];
unsigned char linea1[NUM_BYTES];
unsigned char linea2[NUM_BYTES];
unsigned char linea3[NUM_BYTES];
unsigned char linea4[NUM_BYTES];
unsigned char linea5[NUM_BYTES];
unsigned char linea6[NUM_BYTES];
unsigned char linea7[NUM_BYTES];
unsigned char linea8[NUM_BYTES];
uint32_t cuenta_andv[8];
unsigned char pos[8];
};

struct TIME
{
unsigned char min[3];
unsigned char seg[2];
unsigned char cent[2];
};

/*----------------------------------------------------------------------------
 ACTUALIZA LOS DATOS DESDE LAS UNIDADES INDIVIDUALES
 *---------------------------------------------------------------------------*/
void Actualizar(void)
{
int n;
LPC_UART->IER = IER_THRE | IER_RLS;			/* Disable RBR */
UARTBuffer[0]='A';
UARTSend( (uint8_t *)UARTBuffer, 1 );
UARTCount = 0;
LPC_UART->IER = IER_THRE | IER_RLS | IER_RBR;

LPC_UART->IER = IER_THRE | IER_RLS;			/* Disable RBR */
UARTBuffer[0]=laps;
UARTSend( (uint8_t *)UARTBuffer, 1 );
UARTCount = 0;
LPC_UART->IER = IER_THRE | IER_RLS | IER_RBR;

//Envio estado
LPC_UART->IER = IER_THRE | IER_RLS;			/* Disable RBR */
if(comienzo==SET)
	{
	UARTBuffer[0]='S';
	}
if(comienzo==ADQ)
	{
	UARTBuffer[0]='S';
	}http://www.e-torredebabel.com/Historia-de-la-filosofia/Filosofiacontemporanea/Sartre/Principal-Sartre.htm
if(comienzo==PC_OK)
	{
	UARTBuffer[0]='R';
	}
if(comienzo==FIN)
	{
	UARTBuffer[0]='W';
	}
if(comienzo==VIRGEN)
	{
	UARTBuffer[0]='W';
	}
UARTSend( (uint8_t *)UARTBuffer, 1 );
UARTCount = 0;
LPC_UART->IER = IER_THRE | IER_RLS | IER_RBR;

delay(1000000);
if(UARTCount!=sizeof(uint32_t)+1)
	{
	strcpy(info.linea1,"DESCON  ");
	info.cuenta_andv[0]=9999999;
	estado[0]=DESC;
	UARTCount = 0;
	}
else
	{

	for(n=0;n<4;n++)
		{
		pepe.bytes[n]=UARTBuffer[n];
		}

	info.cuenta_andv[0]=pepe.cuenta[0];	//Guardo la cuenta sin desglosar

	if(UARTBuffer[n]==UI_RUN)
		{
		estado[0]=UI_RUN;
		}
	if(UARTBuffer[n]==UI_FIN || hab_andrv[0]=='0')
		{
		estado[0]=UI_FIN;
		}

	UARTCount = 0;

	//Comienza el armado del ascii a partir de las cuentas recibidas
	aux=pepe.cuenta[0]/1000000;
	resto=pepe.cuenta[0]-1000000*aux;
	info.linea1[0]=aux+0x30;
	aux=resto/100000;
	info.linea1[1]=aux+0x30;
	resto=resto-100000*aux;
	aux=resto/10000;
	info.linea1[2]=aux+0x30;
	resto=resto-10000*aux;
	aux=resto/1000;
	info.linea1[3]=aux+0x30;
	resto=resto-1000*aux;
	aux=resto/100;
	info.linea1[4]=aux+0x30;
	resto=resto-100*aux;
	aux=resto/10;
	info.linea1[5]=aux+0x30;
	resto=resto-10*aux;
	info.linea1[6]=resto+0x30;
	info.linea1[7]=' ';

	}
/****************************************************************/

LPC_UART->IER = IER_THRE | IER_RLS;			/* Disable RBR */
UARTBuffer[0]='B';
UARTSend( (uint8_t *)UARTBuffer, 1 );
UARTCount = 0;
LPC_UART->IER = IER_THRE | IER_RLS | IER_RBR;

LPC_UART->IER = IER_THRE | IER_RLS;			/* Disable RBR */
UARTBuffer[0]=laps;
UARTSend( (uint8_t *)UARTBuffer, 1 );
UARTCount = 0;
LPC_UART->IER = IER_THRE | IER_RLS | IER_RBR;

//Envio estado
LPC_UART->IER = IER_THRE | IER_RLS;			/* Disable RBR */

if(comienzo==SET)
	{
	UARTBuffer[0]='S';
	}
if(comienzo==ADQ)
	{
	UARTBuffer[0]='S';
	}
if(comienzo==PC_OK)
	{
	UARTBuffer[0]='R';
	}
if(comienzo==FIN)
	{
	UARTBuffer[0]='W';
	}
if(comienzo==VIRGEN)
	{
	UARTBuffer[0]='W';
	}


UARTSend( (uint8_t *)UARTBuffer, 1 );
UARTCount = 0;
LPC_UART->IER = IER_THRE | IER_RLS | IER_RBR;

delay(1000000);
if(UARTCount!=sizeof(uint32_t)+1)
	{
		strcpy(info.linea2,"DESCON  ");
		info.cuenta_andv[1]=9999999;
		estado[1]=DESC;
		UARTCount = 0;
	}
else
	{
		for(n=0;n<4;n++)
		{
		pepe.bytes[n]=UARTBuffer[n];
		}


		if(UARTBuffer[n]==UI_RUN)
			{
			estado[1]=UI_RUN;
			}
		if(UARTBuffer[n]==UI_FIN || hab_andrv[1]=='0')
			{
			estado[1]=UI_FIN;
			}

		UARTCount = 0;

		info.cuenta_andv[1]=pepe.cuenta[0];	//Guardo la cuenta sin desglosar

		aux=pepe.cuenta[0]/1000000;
		resto=pepe.cuenta[0]-1000000*aux;
		info.linea2[0]=aux+0x30;
		aux=resto/100000;
		info.linea2[1]=aux+0x30;
		resto=resto-100000*aux;
		aux=resto/10000;
		info.linea2[2]=aux+0x30;
		resto=resto-10000*aux;
		aux=resto/1000;
		info.linea2[3]=aux+0x30;
		resto=resto-1000*aux;
		aux=resto/100;
		info.linea2[4]=aux+0x30;
		resto=resto-100*aux;
		aux=resto/10;
		info.linea2[5]=aux+0x30;
		resto=resto-10*aux;
		info.linea2[6]=resto+0x30;
		info.linea2[7]=' ';
	}

/****************************************************************/

LPC_UART->IER = IER_THRE | IER_RLS;			/* Disable RBR */
UARTBuffer[0]='C';
UARTSend( (uint8_t *)UARTBuffer, 1 );
UARTCount = 0;
LPC_UART->IER = IER_THRE | IER_RLS | IER_RBR;

LPC_UART->IER = IER_THRE | IER_RLS;			/* Disable RBR */
UARTBuffer[0]=laps;
UARTSend( (uint8_t *)UARTBuffer, 1 );
UARTCount = 0;
LPC_UART->IER = IER_THRE | IER_RLS | IER_RBR;

//Envio estado
LPC_UART->IER = IER_THRE | IER_RLS;			/* Disable RBR */
if(comienzo==SET)
	{
	UARTBuffer[0]='S';
	}
if(comienzo==ADQ)
	{
	UARTBuffer[0]='S';
	}
if(comienzo==PC_OK)
	{
	UARTBuffer[0]='R';
	}
if(comienzo==FIN)
	{
	UARTBuffer[0]='W';
	}
if(comienzo==VIRGEN)
	{
	UARTBuffer[0]='W';
	}
UARTSend( (uint8_t *)UARTBuffer, 1 );
UARTCount = 0;
LPC_UART->IER = IER_THRE | IER_RLS | IER_RBR;
//delay(1000000);
if(UARTCount!=sizeof(uint32_t)+1)
	{
		strcpy(info.linea3,"DESCON  ");
		info.cuenta_andv[2]=9999999;
		estado[2]=DESC;
		UARTCount = 0;

	}
else
	{
		for(n=0;n<4;n++)
		{
		pepe.bytes[n]=UARTBuffer[n];
		}

		if(UARTBuffer[n]==UI_RUN)
			{
			estado[2]=UI_RUN;
			}
		if(UARTBuffer[n]==UI_FIN || hab_andrv[2]=='0')
			{
			estado[2]=UI_FIN;
			}

		UARTCount = 0;

		info.cuenta_andv[2]=pepe.cuenta[0];	//Guardo la cuenta sin desglosar

		aux=pepe.cuenta[0]/1000000;
		resto=pepe.cuenta[0]-1000000*aux;
		info.linea3[0]=aux+0x30;
		aux=resto/100000;
		info.linea3[1]=aux+0x30;
		resto=resto-100000*aux;
		aux=resto/10000;
		info.linea3[2]=aux+0x30;
		resto=resto-10000*aux;
		aux=resto/1000;
		info.linea3[3]=aux+0x30;
		resto=resto-1000*aux;
		aux=resto/100;
		info.linea3[4]=aux+0x30;
		resto=resto-100*aux;
		aux=resto/10;
		info.linea3[5]=aux+0x30;
		resto=resto-10*aux;
		info.linea3[6]=resto+0x30;
		info.linea3[7]=' ';
	}

/****************************************************************/

LPC_UART->IER = IER_THRE | IER_RLS;			/* Disable RBR */
UARTBuffer[0]='D';
UARTSend( (uint8_t *)UARTBuffer, 1 );
UARTCount = 0;
LPC_UART->IER = IER_THRE | IER_RLS | IER_RBR;

LPC_UART->IER = IER_THRE | IER_RLS;			/* Disable RBR */
UARTBuffer[0]=laps;
UARTSend( (uint8_t *)UARTBuffer, 1 );
UARTCount = 0;
LPC_UART->IER = IER_THRE | IER_RLS | IER_RBR;

//Envio estado
LPC_UART->IER = IER_THRE | IER_RLS;			/* Disable RBR */
if(comienzo==SET)
	{
	UARTBuffer[0]='S';
	}
if(comienzo==ADQ)
	{
	UARTBuffer[0]='S';
	}
if(comienzo==PC_OK)
	{
	UARTBuffer[0]='R';
	}
if(comienzo==FIN)
	{
	UARTBuffer[0]='W';
	}
if(comienzo==VIRGEN)
	{
	UARTBuffer[0]='W';
	}
UARTSend( (uint8_t *)UARTBuffer, 1 );
UARTCount = 0;
LPC_UART->IER = IER_THRE | IER_RLS | IER_RBR;
//delay(1000000);
if(UARTCount!=sizeof(uint32_t)+1)
	{
		strcpy(info.linea4,"DESCON  ");
		info.cuenta_andv[3]=9999999;
		estado[3]=DESC;
		UARTCount = 0;

	}
else
	{
		for(n=0;n<4;n++)
		{
		pepe.bytes[n]=UARTBuffer[n];
		}

		if(UARTBuffer[n]==UI_RUN)
			{
			estado[3]=UI_RUN;
			}
		if(UARTBuffer[n]==UI_FIN || hab_andrv[3]=='0')
			{
			estado[3]=UI_FIN;
			}

		UARTCount = 0;

		info.cuenta_andv[3]=pepe.cuenta[0];	//Guardo la cuenta sin desglosar

		aux=pepe.cuenta[0]/1000000;
		resto=pepe.cuenta[0]-1000000*aux;
		info.linea4[0]=aux+0x30;
		aux=resto/100000;
		info.linea4[1]=aux+0x30;
		resto=resto-100000*aux;
		aux=resto/10000;
		info.linea4[2]=aux+0x30;
		resto=resto-10000*aux;
		aux=resto/1000;
		info.linea4[3]=aux+0x30;
		resto=resto-1000*aux;
		aux=resto/100;
		info.linea4[4]=aux+0x30;
		resto=resto-100*aux;
		aux=resto/10;
		info.linea4[5]=aux+0x30;
		resto=resto-10*aux;
		info.linea4[6]=resto+0x30;
		info.linea4[7]=' ';
	}

/****************************************************************/

LPC_UART->IER = IER_THRE | IER_RLS;			/* Disable RBR */
UARTBuffer[0]='E';
UARTSend( (uint8_t *)UARTBuffer, 1 );
UARTCount = 0;
LPC_UART->IER = IER_THRE | IER_RLS | IER_RBR;

LPC_UART->IER = IER_THRE | IER_RLS;			/* Disable RBR */
UARTBuffer[0]=laps;
UARTSend( (uint8_t *)UARTBuffer, 1 );
UARTCount = 0;
LPC_UART->IER = IER_THRE | IER_RLS | IER_RBR;

//Envio estado
LPC_UART->IER = IER_THRE | IER_RLS;			/* Disable RBR */
if(comienzo==SET)
	{
	UARTBuffer[0]='S';
	}
if(comienzo==ADQ)
	{
	UARTBuffer[0]='S';
	}
if(comienzo==PC_OK)
	{
	UARTBuffer[0]='R';
	}
if(comienzo==FIN)
	{
	UARTBuffer[0]='W';
	}
if(comienzo==VIRGEN)
	{
	UARTBuffer[0]='W';
	}
UARTSend( (uint8_t *)UARTBuffer, 1 );
UARTCount = 0;
LPC_UART->IER = IER_THRE | IER_RLS | IER_RBR;

//delay(1000000);
if(UARTCount!=sizeof(uint32_t)+1)
	{
		strcpy(info.linea5,"DESCON  ");
		info.cuenta_andv[4]=9999999;
		estado[4]=DESC;
		UARTCount = 0;

	}
else
	{
		for(n=0;n<4;n++)
		{
		pepe.bytes[n]=UARTBuffer[n];
		}
		if(UARTBuffer[n]==UI_RUN)
			{
			estado[4]=UI_RUN;
			}
		if(UARTBuffer[n]==UI_FIN || hab_andrv[4]=='0')
			{
			estado[4]=UI_FIN;
			}

		UARTCount = 0;


		info.cuenta_andv[4]=pepe.cuenta[0];	//Guardo la cuenta sin desglosar

		aux=pepe.cuenta[0]/1000000;
		resto=pepe.cuenta[0]-1000000*aux;
		info.linea5[0]=aux+0x30;
		aux=resto/100000;
		info.linea5[1]=aux+0x30;
		resto=resto-100000*aux;
		aux=resto/10000;
		info.linea5[2]=aux+0x30;
		resto=resto-10000*aux;
		aux=resto/1000;
		info.linea5[3]=aux+0x30;
		resto=resto-1000*aux;
		aux=resto/100;
		info.linea5[4]=aux+0x30;
		resto=resto-100*aux;
		aux=resto/10;
		info.linea5[5]=aux+0x30;
		resto=resto-10*aux;
		info.linea5[6]=resto+0x30;
		info.linea5[7]=' ';
	}

/****************************************************************/

LPC_UART->IER = IER_THRE | IER_RLS;			/* Disable RBR */
UARTBuffer[0]='F';
UARTSend( (uint8_t *)UARTBuffer, 1 );
UARTCount = 0;
LPC_UART->IER = IER_THRE | IER_RLS | IER_RBR;

LPC_UART->IER = IER_THRE | IER_RLS;			/* Disable RBR */
UARTBuffer[0]=laps;
UARTSend( (uint8_t *)UARTBuffer, 1 );
UARTCount = 0;
LPC_UART->IER = IER_THRE | IER_RLS | IER_RBR;

//Envio estado
LPC_UART->IER = IER_THRE | IER_RLS;			/* Disable RBR */
if(comienzo==SET)
	{
		UARTBuffer[0]='S';
	}

if(comienzo==ADQ)
	{
	UARTBuffer[0]='S';
	}
if(comienzo==PC_OK)
	{
	UARTBuffer[0]='R';
	}
if(comienzo==FIN)
	{
	UARTBuffer[0]='W';
	}
if(comienzo==VIRGEN)
	{
	UARTBuffer[0]='W';
	}
UARTSend( (uint8_t *)UARTBuffer, 1 );
UARTCount = 0;
LPC_UART->IER = IER_THRE | IER_RLS | IER_RBR;

//delay(1000000);

if(UARTCount!=sizeof(uint32_t)+1)
	{
		strcpy(info.linea6,"DESCON  ");
		info.cuenta_andv[5]=9999999;
		estado[5]=DESC;
		UARTCount = 0;

	}
else
	{
		for(n=0;n<4;n++)
		{
		pepe.bytes[n]=UARTBuffer[n];
		}

		if(UARTBuffer[n]==UI_RUN)
			{
			estado[5]=UI_RUN;
			}
		if(UARTBuffer[n]==UI_FIN || hab_andrv[5]=='0')
			{
			estado[5]=UI_FIN;
			}

		UARTCount = 0;

		info.cuenta_andv[5]=pepe.cuenta[0];	//Guardo la cuenta sin desglosar

		aux=pepe.cuenta[0]/1000000;
		resto=pepe.cuenta[0]-1000000*aux;
		info.linea6[0]=aux+0x30;
		aux=resto/100000;
		info.linea6[1]=aux+0x30;
		resto=resto-100000*aux;
		aux=resto/10000;
		info.linea6[2]=aux+0x30;
		resto=resto-10000*aux;
		aux=resto/1000;
		info.linea6[3]=aux+0x30;
		resto=resto-1000*aux;
		aux=resto/100;
		info.linea6[4]=aux+0x30;
		resto=resto-100*aux;
		aux=resto/10;
		info.linea6[5]=aux+0x30;
		resto=resto-10*aux;
		info.linea6[6]=resto+0x30;
		info.linea6[7]=' ';
	}

/****************************************************************/

LPC_UART->IER = IER_THRE | IER_RLS;			/* Disable RBR */
UARTBuffer[0]='G';
UARTSend( (uint8_t *)UARTBuffer, 1 );
UARTCount = 0;
LPC_UART->IER = IER_THRE | IER_RLS | IER_RBR;

LPC_UART->IER = IER_THRE | IER_RLS;			/* Disable RBR */
UARTBuffer[0]=laps;
UARTSend( (uint8_t *)UARTBuffer, 1 );
UARTCount = 0;
LPC_UART->IER = IER_THRE | IER_RLS | IER_RBR;

LPC_UART->IER = IER_THRE | IER_RLS;			/* Disable RBR */
if(comienzo==SET)
	{
		UARTBuffer[0]='S';
	}

if(comienzo==ADQ)
	{
	UARTBuffer[0]='S';
	}
if(comienzo==PC_OK)
	{
	UARTBuffer[0]='R';
	}
if(comienzo==FIN)
	{
	UARTBuffer[0]='W';
	}
if(comienzo==VIRGEN)
	{
	UARTBuffer[0]='W';
	}
UARTSend( (uint8_t *)UARTBuffer, 1 );
UARTCount = 0;
LPC_UART->IER = IER_THRE | IER_RLS | IER_RBR;

//delay(1000000);
if(UARTCount!=sizeof(uint32_t)+1)
	{
		strcpy(info.linea7,"DESCON  ");
		info.cuenta_andv[6]=9999999;
		estado[6]=DESC;
		UARTCount = 0;

	}
else
	{
		for(n=0;n<4;n++)
		{
		pepe.bytes[n]=UARTBuffer[n];
		}

		if(UARTBuffer[n]==UI_RUN)
			{
			estado[6]=UI_RUN;
			}
		if(UARTBuffer[n]==UI_FIN || hab_andrv[6]=='0')
			{
			estado[6]=UI_FIN;
			}

		UARTCount = 0;

		info.cuenta_andv[6]=pepe.cuenta[0];	//Guardo la cuenta sin desglosar

		aux=pepe.cuenta[0]/1000000;
		resto=pepe.cuenta[0]-1000000*aux;
		info.linea7[0]=aux+0x30;
		aux=resto/100000;
		info.linea7[1]=aux+0x30;
		resto=resto-100000*aux;
		aux=resto/10000;
		info.linea7[2]=aux+0x30;
		resto=resto-10000*aux;
		aux=resto/1000;
		info.linea7[3]=aux+0x30;
		resto=resto-1000*aux;
		aux=resto/100;
		info.linea7[4]=aux+0x30;
		resto=resto-100*aux;
		aux=resto/10;
		info.linea7[5]=aux+0x30;
		resto=resto-10*aux;
		info.linea7[6]=resto+0x30;
		info.linea7[7]=' ';
	}

/****************************************************************/
//Envio ID
LPC_UART->IER = IER_THRE | IER_RLS;			/* Disable RBR */
UARTBuffer[0]='H';
UARTSend( (uint8_t *)UARTBuffer, 1 );
UARTCount = 0;
LPC_UART->IER = IER_THRE | IER_RLS | IER_RBR;
//Envio laps
LPC_UART->IER = IER_THRE | IER_RLS;			/* Disable RBR */
UARTBuffer[0]=laps;
UARTSend( (uint8_t *)UARTBuffer, 1 );
UARTCount = 0;
LPC_UART->IER = IER_THRE | IER_RLS | IER_RBR;
//Envio estado
LPC_UART->IER = IER_THRE | IER_RLS;			/* Disable RBR */
if(comienzo==SET)
	{
		UARTBuffer[0]='S';
	}

if(comienzo==ADQ)
	{
	UARTBuffer[0]='S';
	}
if(comienzo==PC_OK)
	{
	UARTBuffer[0]='R';
	}
if(comienzo==FIN)
	{
	UARTBuffer[0]='W';
	}
if(comienzo==VIRGEN)
	{
	UARTBuffer[0]='W';
	}
UARTSend( (uint8_t *)UARTBuffer, 1 );
UARTCount = 0;
LPC_UART->IER = IER_THRE | IER_RLS | IER_RBR;

//delay(1000000);

if(UARTCount!=sizeof(uint32_t)+1)
	{
	strcpy(info.linea8,"DESCON  ");
	info.cuenta_andv[7]=9999999;
	estado[7]=DESC;
	UARTCount = 0;
	}
else
	{
		for(n=0;n<4;n++)
		{
		pepe.bytes[n]=UARTBuffer[n];
		}

		if(UARTBuffer[n]==UI_RUN)
		{
		estado[7]=UI_RUN;
		}
		if(UARTBuffer[n]==UI_FIN || hab_andrv[7]=='0')
		{
		estado[7]=UI_FIN;
		}

		UARTCount = 0;

		info.cuenta_andv[7]=pepe.cuenta[0];	//Guardo la cuenta sin desglosar

		aux=pepe.cuenta[0]/1000000;
		resto=pepe.cuenta[0]-1000000*aux;
		info.linea8[0]=aux+0x30;
		aux=resto/100000;
		info.linea8[1]=aux+0x30;
		resto=resto-100000*aux;
		aux=resto/10000;
		info.linea8[2]=aux+0x30;
		resto=resto-10000*aux;
		aux=resto/1000;
		info.linea8[3]=aux+0x30;
		resto=resto-1000*aux;
		aux=resto/100;
		info.linea8[4]=aux+0x30;
		resto=resto-100*aux;
		aux=resto/10;
		info.linea8[5]=aux+0x30;
		resto=resto-10*aux;
		info.linea8[6]=resto+0x30;
		info.linea8[7]=' ';
	}
aux=0;
for(n=0;n<8;n++)
{
	if(estado[n]==UI_FIN)
	{
		aux++;
	}
}
if(aux==8)		//Todas las unidades terminaron
{
	comienzo=FIN;
}
}

/*----------------------------------------------------------------------------
 Initializes the VCOM port.
 Call this function before using VCOM_putchar or VCOM_getchar
 *---------------------------------------------------------------------------*/
void VCOM_Init(void) {

  CDC_Init ();
}

/*----------------------------------------------------------------------------
  Envia los 32 bytes del array buffer por USB hacia la PC
 *---------------------------------------------------------------------------*/
void Enviar_Datos_USB(unsigned char *puntero)
{
aux=0;
while(aux!='S')
  {
	  Lee_USB();					//Espera a que se de comienzo a la tx
  }
CDC_DepInEmpty = 0;
USB_WriteEP (CDC_DEP_IN, (unsigned  char *)puntero,NUM_BYTES);
}

/*----------------------------------------------------------------------------
 *Lee un caracter desde USB
 *---------------------------------------------------------------------------*/
void Lee_USB(void)
{
static char serBuf [32];
int  numBytesToRead, numBytesRead, numAvailByte,n;

CDC_OutBufAvailChar (&numAvailByte);
if (numAvailByte > 0)
{
	numBytesToRead = numAvailByte > 32 ? 32 : numAvailByte;
	numBytesRead = CDC_RdOutBuf (&serBuf[0], &numBytesToRead);
	aux=serBuf[0];											//El caracter recibido se guarda en aux
	if(inicializacion==0)
	{
	if(aux>='0')
		{
		start=NLAPS_OK;
		}
	if(aux=='S')
		{
		start=OK;
		}
	if(numBytesRead==8)	//Indica que se han recibido los estados de habilitacion de cada andarivel
		{
		for(n=0;n<8;n++)
		{
			hab_andrv[n]=serBuf[n];
		}
		}
	}

}

}
/*----------------------------------------------------------------------------
ORDENA LOS TIEMPOS E INDICA LA POSICION DE CADA ANDARIVEL
*---------------------------------------------------------------------------*/
void Ordenar()
{
	int i,k;
	uint32_t muleto;
	unsigned char aux;
	for(i=0;i<8;i++)
	{
		info.pos[i]=i+0x31;
	}

	for(i=1;i<8;i++)
	{
		for(k=0;k<8-i;k++)
		{
			if(info.cuenta_andv[k]>info.cuenta_andv[k+1])
			{
				muleto=info.cuenta_andv[k];
				info.cuenta_andv[k]=info.cuenta_andv[k+1];
				info.cuenta_andv[k+1]=muleto;
				aux=info.pos[k];
				info.pos[k]=info.pos[k+1];
				info.pos[k+1]=aux;
			}
		}
	}

}

/*----------------------------------------------------------------------------
  Main Program
 *---------------------------------------------------------------------------*/
int main (void) {
	  	/* Enable Timer32_1, IOCON, and USB blocks */
int m;
LPC_SYSCON->SYSAHBCLKCTRL |= (EN_TIMER32_1 | EN_IOCON | EN_USBREG);

init_timer32(0, TIME_INTERVAL);				//TIME_INTERVAL está en timer32.h. Leer los comentarios para definir la frecuencia
GPIOInit();
GPIOSetDir( 2, 0, 1 );
//P2.2: Boton de Comienzo
GPIOSetDir( PORT2, 2, 0 ); 					//Configura P2.0 como entrada
GPIOSetInterrupt( PORT2, 2, 1, 0, 0 ); 		//Ahora además de ser entrada, es de interrupcion.
GPIOIntEnable( PORT2, 2 );					//Habilita las interrupciones.

//P2.4: Boton de start
GPIOSetDir( PORT2, 4, 0 ); 					//Configura P2.0 como entrada
GPIOSetInterrupt( PORT2, 4, 0, 0, 0 ); 		//Ahora además de ser entrada, es de interrupcion.
//GPIOIntEnable( PORT2, 1 );					//Habilita las interrupciones.

enable_timer32(0);							//Habilita el timer.
GPIOSetValue( 2, 0, 0 );
USBIOClkConfig();
VCOM_Init();                              // VCOM Initialization
UARTInit(9600);
USB_Init();                               // USB Initialization
USB_Connect(TRUE);                        // USB Connect
while (!USB_Configuration) ;              // wait until USB is configured

strcpy(info.estado,"ESTADO  ");
comienzo=VIRGEN;
while (1)
	{			                               // Loop forever
	//Espero el numero de laps
	while(start!=NLAPS_OK)
		{
		Lee_USB();		  					//Espera a que se de comienzo a la tx
		}
	if(aux=='R')
	{
		comienzo=PC_OK;
	}
	else
	{
		laps=aux;
	}
	aux=0;
	strcpy(info.estado,"PCOK    ");
	if(comienzo==VIRGEN)
		{
		comienzo=PC_OK;
		}
	if(comienzo==SET)
		{
		strcpy(info.estado,"SET     ");
		}
	if(comienzo==ADQ)
		{
		strcpy(info.estado,"ADQ     ");
		}
	if(comienzo==FIN)
		{
		strcpy(info.estado,"FIN     ");
		}
	//Envio el flag para que continue el programa en la pc
	aux='C';
	CDC_DepInEmpty = 0;
	USB_WriteEP (CDC_DEP_IN, &aux,1);


	Actualizar();
	Ordenar();
/****************************************************************************
 * Comienzo indica el estado en el que se encuentra el sistema.
 *
 *		*-PC_OK: Indica que la PC envio el numero de laps y esta lista para comenzar
 *		*-SET: Indica que se presiono el boton de comienzo y se esta esperando a que el juez comience la
 *		competencia.
 *		*-ADQ: Indica que la competencia se ha iniciado y se esta llevando a cabo la adquisicion de tiempos.
 *		*-FIN: Indica que todas las UIs conectadas han finalizado la toma de tiempos.
 *		*-RESET: Indica que se ha reseteado el equipo. Esto se logra teniendo presionado por mas de
 *		dos segundos el boton de comienzo en la unidad central.
 *
 ****************************************************************************/
		aux='C';
		CDC_DepInEmpty = 0;
		USB_WriteEP (CDC_DEP_IN, &aux,1);
		Enviar_Datos_USB(&info.estado[0]);
		Enviar_Datos_USB(&info.linea1[0]);
		Enviar_Datos_USB(&info.linea2[0]);
		Enviar_Datos_USB(&info.linea3[0]);
		Enviar_Datos_USB(&info.linea4[0]);
		Enviar_Datos_USB(&info.linea5[0]);
		Enviar_Datos_USB(&info.linea6[0]);
		Enviar_Datos_USB(&info.linea7[0]);
		Enviar_Datos_USB(&info.linea8[0]);
		Enviar_Datos_USB(&info.pos[0]);
		GPIOIntEnable( PORT2, 2 );		//Vuelvo a habilitar la interrupcion del boton de comienzo.

		//}
	aux=0;
	start=0;
	} // end while
} // end main ()

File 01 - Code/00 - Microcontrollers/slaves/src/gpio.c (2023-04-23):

/*****************************************************************************
 *   gpio.c:  GPIO C file for NXP LPC13xx Family Microprocessors
 *
 *   Copyright(C) 2008, NXP Semiconductor
 *   All rights reserved.
 *
 *   History
 *   2008.07.20  ver 1.00    Preliminary version, first Release
 *   2009.12.09  ver 1.05    Mod to use mask registers for GPIO writes + inlining (.h)
 *
*****************************************************************************/
#include "LPC13xx.h"			/* LPC13xx Peripheral Registers */
#include "gpio.h"

/* ===================
 * CodeRed - Modified file to extract out interrupt handler related code,
 * which is really application project specific.
 * Set GPIO_GENERIC_INTS to 1 to reenable original code.
 * =================== */

//#define GPIO_GENERIC_INTS 1

#ifdef GPIO_GENERIC_INTS
volatile uint32_t gpio0_counter = 0;
volatile uint32_t gpio1_counter = 0;
volatile uint32_t gpio2_counter = 0;
volatile uint32_t gpio3_counter = 0;
volatile uint32_t p0_1_counter  = 0;
volatile uint32_t p1_1_counter  = 0;
volatile uint32_t p2_1_counter  = 0;
volatile uint32_t p3_1_counter  = 0;

/*****************************************************************************
** Function name:		PIOINT0_IRQHandler
**
** Descriptions:		Use one GPIO pin(port0 pin1) as interrupt source
**
** parameters:			None
** Returned value:		None
** 
*****************************************************************************/
void PIOINT0_IRQHandler(void)
{
  uint32_t regVal;

  gpio0_counter++;
  regVal = GPIOIntStatus( PORT0, 1 );
  if ( regVal )
  {
	p0_1_counter++;
	GPIOIntClear( PORT0, 1 );
  }		
  return;
}

/*****************************************************************************
** Function name:		PIOINT1_IRQHandler
**
** Descriptions:		Use one GPIO pin(port1 pin1) as interrupt source
**
** parameters:			None
** Returned value:		None
** 
*****************************************************************************/
void PIOINT1_IRQHandler(void)
{
  uint32_t regVal;

  gpio1_counter++;
  regVal = GPIOIntStatus( PORT1, 1 );
  if ( regVal )
  {
	p1_1_counter++;
	GPIOIntClear( PORT1, 1 );
  }		
  return;
}

/*****************************************************************************
** Function name:		PIOINT2_IRQHandler
**
** Descriptions:		Use one GPIO pin(port2 pin1) as interrupt source
**
** parameters:			None
** Returned value:		None
** 
*****************************************************************************/
void PIOINT2_IRQHandler(void)
{
  uint32_t regVal;

  gpio2_counter++;
  regVal = GPIOIntStatus( PORT2, 1 );
  if ( regVal )
  {
	p2_1_counter++;
	GPIOIntClear( PORT2, 1 );
  }		
  return;
}

/*****************************************************************************
** Function name:		PIOINT3_IRQHandler
**
** Descriptions:		Use one GPIO pin(port3 pin1) as interrupt source
**
** parameters:			None
** Returned value:		None
** 
*****************************************************************************/
void PIOINT3_IRQHandler(void)
{
  uint32_t regVal;

  gpio3_counter++;
  regVal = GPIOIntStatus( PORT3, 1 );
  if ( regVal )
  {
	p3_1_counter++;
	GPIOIntClear( PORT3, 1 );
  }		
  return;
}
#endif //GPIO_GENERIC_INTS

/*****************************************************************************
** Function name:		GPIOInit
**
** Descriptions:		Initialize GPIO, install the
**						GPIO interrupt handler
**
** parameters:			None
** Returned value:		true or false, return false if the VIC table
**						is full and GPIO interrupt handler can be
**						installed.
** 
*****************************************************************************/
void GPIOInit( void )
{
  /* Enable AHB clock to the GPIO domain. */
  LPC_SYSCON->SYSAHBCLKCTRL |= (1<<6);

#ifdef __JTAG_DISABLED  
  LPC_IOCON->JTAG_TDO_PIO1_1  &= ~0x07;
  LPC_IOCON->JTAG_TDO_PIO1_1  |= 0x01;
#endif

  /* Set up NVIC when I/O pins are configured as external interrupts. */
  NVIC_EnableIRQ(EINT0_IRQn);
  NVIC_EnableIRQ(EINT1_IRQn);
  NVIC_EnableIRQ(EINT2_IRQn);
  NVIC_EnableIRQ(EINT3_IRQn);
  return;
}
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

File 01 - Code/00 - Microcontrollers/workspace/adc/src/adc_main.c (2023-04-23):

/*****************************************************************************
 *   adctest.c:  main C entry file for NXP LPC13xx Family Microprocessors
 *
 *   Copyright(C) 2008, NXP Semiconductor
 *   All rights reserved.
 *
 *   History
 *   2008.07.19  ver 1.00    Preliminary version, first Release
 *
******************************************************************************/
#include "LPC13xx.h"                        /* LPC13xx definitions */
#include "adc.h"
#ifdef ADC_DEBUG
#include "stdio.h"
#endif

extern volatile uint32_t ADCValue[ADC_NUM];
extern volatile uint32_t ADCIntDone;

#ifdef ADC_DEBUG
uint8_t ConvertDigital ( uint8_t digital )
{
  uint8_t ascii_char;

  if ( (digital >= 0) && (digital <= 9) )
  {
	ascii_char = digital + 0x30;	/* 0~9 */
  }
  else
  {
	ascii_char = digital - 0x0A;
	ascii_char += 0x41;				/* A~F */
  }
  return ( ascii_char );
}
#endif

#ifdef ADC_DEBUG
#define BAR_OUTPUT_LENGTH 60
#define ADC_COUNT_MAX 1023
#define CHANNEL_WIDTH 2
#define VOLT_WIDTH 4
#define MAX_BAR_LENGTH (BAR_OUTPUT_LENGTH-CHANNEL_WIDTH-1-VOLT_WIDTH-1-2)
#define SUPPLY_VOLTAGE 3.30

void FillString(char *s, char c, uint32_t len)
{
	if(!len)
		goto empty;
	while(--len)
		*s++ = c;
empty:
	*s = 0;
}
void ADCBar(int32_t Channel, uint32_t Counts)
{
	uint32_t ValueBarLen = Counts*MAX_BAR_LENGTH/ADC_COUNT_MAX;
	char ValueBarBuf[BAR_OUTPUT_LENGTH+1];
	float ValueVolts = Counts*SUPPLY_VOLTAGE/ADC_COUNT_MAX;

	if(Channel == 0)
	{
		FillString(ValueBarBuf, '-', MAX_BAR_LENGTH+2);
		printf("%-9s%s\n", "", ValueBarBuf);
	}

	if(Channel >= 0)
	{
		FillString(ValueBarBuf, '#', ValueBarLen);
		printf("%2d %d.%02dV |%s%-*s|\n", Channel,
				(int)ValueVolts, (int)((ValueVolts-(int)ValueVolts)*100),
				ValueBarBuf, MAX_BAR_LENGTH-ValueBarLen, "");
	}
	else
	{
		FillString(ValueBarBuf, '-', MAX_BAR_LENGTH+2);
		printf("%-9s%s\n", "", ValueBarBuf);
	}
}
#endif

/******************************************************************************
**   Main Function  main()
******************************************************************************/
int main (void)
{
	 /* Basic chip initialization is taken care of in SystemInit() called
	   * from the startup code. SystemInit() and chip settings are defined
	   * in the CMSIS system_<part family>.c file.
	   */

  uint32_t i;

  /* Initialize ADC  */
  ADCInit( ADC_CLK );

#if BURST_MODE				/* Interrupt driven only */
  ADCBurstRead();
  while ( !ADCIntDone );
  ADCIntDone = 0;
#else
  for ( i = 0; i < ADC_NUM; i++ )
  {
#if ADC_INTERRUPT_FLAG				/* Interrupt driven */
	ADCRead( i );
	while ( !ADCIntDone );
	ADCIntDone = 0;
#else
	ADCValue[i] = ADCRead( i );	/* Polling */
#endif
#ifdef ADC_DEBUG
	// Note: a single printf call can add 10k to code size
	ADCBar(i, ADCValue[i]);
//	printf("ADC[%d] = %05d\r\n", i, ADCValue[i]);
#endif
  }
#ifdef ADC_DEBUG
  ADCBar(-1, 0);
#endif
#endif
  while(1);
}

/******************************************************************************
**                            End Of File
******************************************************************************/

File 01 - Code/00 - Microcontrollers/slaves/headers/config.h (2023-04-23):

/*****************************************************************************
 *   config.h:  config file for blinky example for NXP LPC13xx Family
 *   Microprocessors
 *
 *   Copyright(C) 2008, NXP Semiconductor
 *   All rights reserved.
 *
 *   History
 *   2008.07.19  ver 1.00    Preliminary version, first Release
 *
******************************************************************************/

/*
Overview:
   This example shows how to use a timer to blink an LED. It works by using
   libLPC to configure a I/O port and a 32-bit timer, then setting up a timer
   interrupt to increment a counter. The main loop polls the counter to
   determine when to toggle the LED state.

User #defines:
   LED_PORT	I/O port driving an LED
   LED_BIT  I/O port bit driving an LED
   LED_ON   Value to set the bit to turn on the LED
   LED_OFF  Value to set the bit to turn off the LED
   LED_TOGGLE_TICKS
		    Number of timer ticks per flash. The timer is configured to generate
		    an interrupt 100 times a second or every 10mS.

How to use:
   Click the debug toolbar button.

   * You should see an LED flashing.
*/

#define LED_PORT 0		// Port for led
#define LED_BIT 7		// Bit on port for led
#define LED_ON 1		// Level to set port to turn on led
#define LED_OFF 0		// Level to set port to turn off led
//#define LED_TOGGLE_TICKS 100 // 100 ticks = 1 Hz flash rate

/*********************************************************************************
**                            End Of File
*********************************************************************************/
